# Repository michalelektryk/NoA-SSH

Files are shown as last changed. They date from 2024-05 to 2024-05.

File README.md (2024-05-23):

# Noise of Antimatter - Subshaper
## disclaimer
This repository contains all files required to make or repair the SSH. The following files are provided as is, with no responsibility. They're provided for personal use only. If you'd like to sell anything made out of them feel free to ping me, I'm mostly ok, as long as you're not big company scamming small manufacturers :)
## Module description
SSH is 16HP triple waveshaper with subharmonicon and sequencer. It's versatile tool for enriching sound sources and animating voices. More information can be found on [the webpage](https://noiseofantimatter.com/modules/ssh_module/) or by checking out [the demo](https://www.youtube.com/watch?v=Nd7Cz19s0W0).
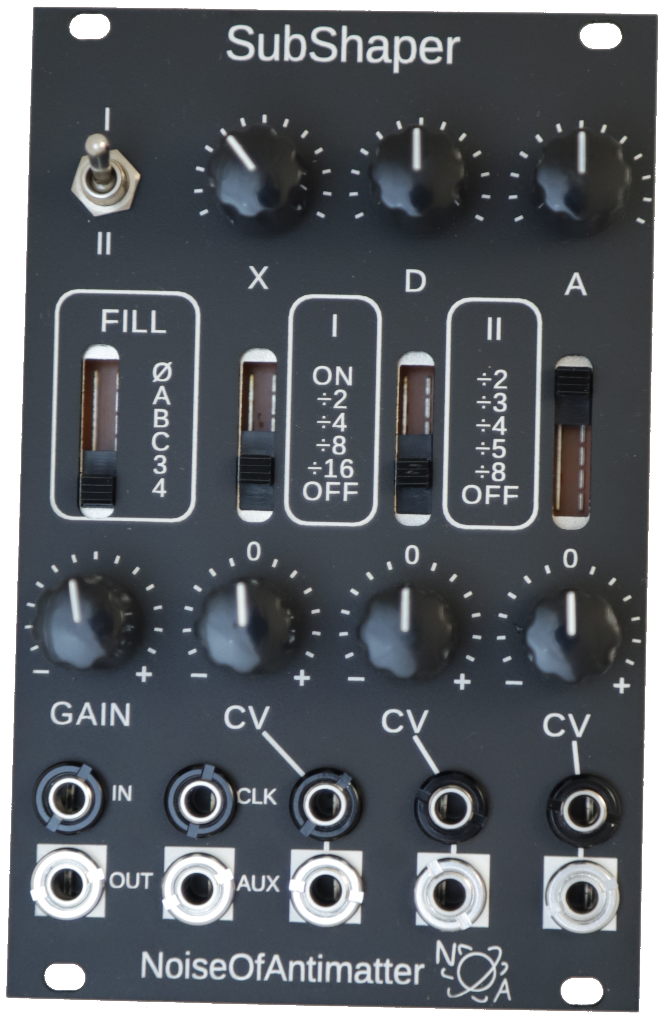
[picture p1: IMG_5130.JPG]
photo of the module


## File structure
- electronics design can be found in folder [electronics](/electronics)
  - schematic.pdf is useful for quick look. For editing and deep dive full kicad design is provided. Project was done in kicad 6 but seems to work equally well in 7/8
- CPDL firmware is provided in folder [greenpak](/greenpak)
  - the device hides all complex digital logic into two greenpak CPLDs.
  - Their configuration and ESP32 software used for flashing are here
- panel design can be found in folder [panel](/panel)
  - panel has been designed as 3d model in openSCAD. Two projections are available for CNC production. Additionally, stls for dual color printing are provided
- manual generating files and pdf can be found in [manual](/manual)
  - It's written in LaTeX. For people who don't know LaTeX I recommend you read about it, especially if you're doing group projects and need to git proper documents

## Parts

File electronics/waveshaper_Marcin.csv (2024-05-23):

Id | Designator | Package | Quantity | Designation | Supplier and ref
1 | U17 | SOT-23-5 | 1 | AP331A
2 | U16,U13 | TSSOP-20_4.4x6.5mm_P0.65mm | 2 | SLG46824
3 | U15,U12,U11,U8,U7,U5,U4,U3,U2,U1 | SOIC-8_3.9x4.9mm_P1.27mm | 10 | TL072
4 | U14 | SOP-16_3.9x9.9mm_P1.27mm | 1 | CD4053B
5 | U10 | SOT-89-3 | 1 | L79L05_SOT89
6 | U9 | SOT-89-3 | 1 | L78L05_SOT89
7 | U6 | SOIC-16_3.9x9.9mm_P1.27mm | 1 | AS3363
8 | SW1 | SS-16F03 | 1 | bank_switch
9 | S4 | SS-16F03 | 1 | channel_3
10 | S3 | SS-16F03 | 1 | channel_2
11 | S2 | SS-16F03 | 1 | channel_1
12 | S1 | SS-16F03 | 1 | fill_switch
13 | RV8 | alpha_pot | 1 | gain
14 | RV7,RV5,RV3,RV1 | alpha_pot | 4 | 10k
15 | RV6,RV4,RV2 | alpha_pot | 3 | param
16 | R71,R69,R66,R64,R63,R62,R61,R60,R59,R57,R54,R53,R52,R51,R50,R49,R48,R47,R36,R34,R26,R23,R22,R21,R20,R19,R18,R17,R16,R14,R13,R12,R11,R10,R9,R8,R7,R6,R5,R4,R3,R2,R1 | R_0603_1608Metric | 43 | 100k
17 | R70,R68,R58,R56 | R_0603_1608Metric | 4 | 400
18 | R67,R46,R37,R32,R30,R29,R28,R27 | R_0603_1608Metric | 8 | 1k
19 | R55,R45,R44,R42,R41,R40,R31,R25,R24 | R_0603_1608Metric | 9 | 10k
20 | R43,R35,R33 | R_0603_1608Metric | 3 | 250k
21 | R39,R38 | R_0603_1608Metric | 2 | 47k
22 | R15 | R_0603_1608Metric | 1 | 20k
23 | JP3,JP2,JP1 | SolderJumper-2_P1.3mm_Open_RoundedPad1.0x1.5mm | 3 | Jumper
24 | J11,J10,J9,J8,J7,J6 | thonkiconn | 6 | AudioJack2_SwitchT
25 | J5 | PinHeader_1x06_P2.54mm_Vertical | 1 | Conn_01x06_Male
26 | J4 | IDC-Header_2x05_P2.54mm_Vertical | 1 | Conn_02x05_Odd_Even
27 | J3 | thonkiconn | 1 | CV3
28 | J2 | thonkiconn | 1 | CV2
29 | J1 | thonkiconn | 1 | CV1
30 | F2,F1 | Fuse_0805_2012Metric | 2 | Polyfuse
31 | D4,D3,D2,D1 | SOT-363_SC-70-6 | 4 | BAV199DW
32 | C27,C26,C25,C24,C21,C20,C19,C18,C15,C14,C13,C12,C2,C1 | C_0603_1608Metric | 14 | 100n
33 | C23,C22,C17,C16 | C_0603_1608Metric | 4 | 100p
34 | C11 | C_0603_1608Metric | 1 | 10u
35 | C10,C9,C8,C7,C6,C5,C4,C3 | C_0805_2012Metric | 8 | 10u

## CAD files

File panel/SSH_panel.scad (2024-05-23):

HP=5.08;
angle=135;
spacing=9.5; //TODO
$fn=20;
draw_jack_plugs=false;

module obwodka(size,diam,width)
{
    difference()
    {
        hull()
        {
            for(x=[diam,size[0]-diam])
            for(y=[diam,size[1]-diam])
                translate([x,y])
                circle(r=diam);
        }
        hull()
        {
            for(x=[diam,size[0]-diam])
            for(y=[diam,size[1]-diam])
                translate([x,y])
                circle(r=diam-width);
        }
    }
}

module panel(n)
{
    difference()
    {
        translate([0.1,0,0])
        cube([n*HP-0.2,128.5,3]);
        for(x=[1.5*HP,(n-1.5)*HP])
        for(y=[3,125.5])
            translate([x,y,-1])
            hull()
            {
                translate([-1,0,0])
                cylinder(r=1.6,h=10);
                translate([1,0,0])
                cylinder(r=1.6,h=10);
            }
    }
}

module jack_in(cut)
{
    if(cut)
        translate([0,0,-1])
        cylinder(d=6.2,h=10);
    else
        translate([0,0,0])
        color("grey")
        difference()
        {
            cylinder(d=6.2,h=4);
            translate([0,0,-1])
            cylinder(d=5,h=6);
        }
}

module jack_out(cut)
{
   
   
    if(cut)
    {  
        translate([0,0,-1])
        cylinder(d=6.2,h=10);
    }
    else
        translate([0,0,0])
        color("grey")
        difference()
        {
            cylinder(d=6.2,h=4);
            translate([0,0,-1])
            cylinder(d=5,h=6);
        }
}


module pot(cut,col="green")
{
    if(cut)
        translate([0,0,-1])
        cylinder(d=7.1,h=10);
    else
        translate([0,0,3.5])
        union()
        {
            color("grey")
            cylinder(d=16,h=4.5);
            color("grey")
            cylinder(d1=13,d2=11,h=17);
            color(col)
            translate([0,4.5,9])
            cube([1.2,4,17],true);
            color(col)
            translate([0,0,15.5])
            intersection()
            {
                cylinder(h=2,d=7);
                translate([0,-3.5,0])
                cube([7,7,7],true);
            }
        }
}

module switch6(cut)
{
    if(cut)
    {
    
    //had to round corners with 3mm radius to deal with milling process    //cube([0.2+3.8+5*3,0.2+4.2,8],true);
        hull()
        for(x=[-0.5,0.5])
        for(y=[-0.5,0.5])
            translate([x*(0.2+3.8+5*3),y*(0.2+4.2-3),-4])
            cylinder(d=3,h=8);
    }
    else
        color("grey")
        translate([0,0,3.5+4.5/2])
        cube([0.2+3.8,0.2+4.2,4.5],true);
       
}

module toggle(cut)
{
    if(cut)
        translate([0,0,-1])
        cylinder(d=6.3,h=10);
    else
        rotate([0,30,90])
        cylinder(d=4,h=10);
}

module arrow_in()
{
    translate([-1,0,0])
    square([3,0.5],true);
    translate([1,0,0])
    for(i=[-1,1])
    rotate(40*i)
    translate([-0.7,0])
    square([1.5,0.5],true);
    difference()
    {
        circle(d=4);
        circle(d=3);
    }
}

module arrow_out()
{
    translate([-1.5,0,0])
    square([3,0.5],true);
    translate([-3.5,0,0])
    for(i=[-1,1])
    rotate(40*i)
    translate([0.7,0])
    square([1.5,0.5],true);
    difference()
    {
        circle(d=4);
        circle(d=3);
    }
}

module opis_atenuv(normalizowane_do_0)
{
    translate([0,spacing])
    if (normalizowane_do_0>0){
        difference()
            {
            text("0",size=2.5,halign="center",valign="center");
            }
        }
    rotate(-angle)
    translate([0,spacing])
    {
        rotate(angle)
        square([2,0.4],true);
        rotate(angle)
        square([0.4,2],true);
    }
    rotate(angle)
    translate([0,spacing])
    {
        rotate(-angle)
        square([2,0.4],true);
    }
}

module opis_galek(not_middle)
{
    ile=6;
    for(i=[-ile:ile])
        if(i!=0 || not_middle<1)
            rotate(i*angle/(ile+1))
            translate([0,spacing-1])
            square([0.4,1],true);
}

switch_level=73;
lower_element=48;
higher_element=105;

module elementy_sub(cut)
{
    for(x=[1:3])
        translate([HP*(2+4*x),0,0])
        {
            translate([0,lower_element,0])
            pot(cut);
            translate([0,switch_level,0])
            rotate([0,0,90])
            switch6(cut);
            translate([0,higher_element,0])
            pot(cut);
        }        
    translate([HP*2,switch_level,0])
    rotate([0,0,90])
    switch6(cut);
    translate([HP*2,higher_element,0])
    toggle(cut);
    translate([HP*2,lower_element,0])
    pot(cut);
    for(x=[0:4])
    {
        translate([16/5*HP*(0.5+x),15,0])
        {
        jack_out(cut);
        if(draw_jack_plugs)
            color("blue")
            cylinder(d=10,h=15);
       
        }
        translate([16/5*HP*(0.5+x),26,0])
        jack_in(cut);
       
       
    }
   
}

SSH_font="Latin modern";

//off spaces to U+2006  SIX-PER-EM SPACE
bankA=["ON","÷2","÷4","÷8","÷16","OFF"];
bankB=["÷2","÷3","÷4","÷5","÷8","OFF"];
control=["Ø","X","D","A","3","4"];
switch=["II","I"];
param=["X","D","A"];
higher_jacks=["IN", "CLK"];
lower_jacks=["OUT", "AUX"];
dodatek=7;

module napisy()
//wszystkie napisy ida tutaj!!!
translate([0,0,3])
linear_extrude(0.2)
{
    opisyBankowSize=2.5;
    //bank 1 slider opisy
    for(i=[0:5])
        translate([HP*8,switch_level-3*(i-2.5)])
        text(bankA[i],size=opisyBankowSize,halign="center",valign="center",spacing=1.1);
    translate([HP*8,switch_level+14])
    text(switch[1],size=3,halign="center",valign="center");
    //bank 2 slider opisy
    for(i=[0:5])
        translate([HP*12,switch_level-3*(i-2.5)])
        text(bankB[i],size=opisyBankowSize,halign="center",valign="center",spacing=1.1);
    translate([HP*12,switch_level+14])
    text(switch[0],size=3,halign="center",valign="center");
    //control slider opisy
    for(i=[0:5])
        translate([HP*4-2,switch_level-3*(i-2.5)])
        text(control[i],size=opisyBankowSize,halign="center",valign="center",spacing=1.1);
    //control slider napis
    translate([HP*3+5.25/2-dodatek/2,switch_level+14])
    text("FILL",size=3,halign="center",valign="center",spacing=1.1);
    //bank switch napisy
    for(i=[0,1])
        translate([HP*2,higher_element-8+8*2*i])
        text(switch[i],size=3,halign="center",valign="center");
    /*translate([HP*2-5,higher_element])
    text("BANK",size=3,halign="center",valign="center",direction="ttb");*/
    //napisy pod atenuvertery
    for(i=[0:3])
    translate([HP*(2+4*i),lower_element])
    {
        if(i!=0)
            translate([0,-12])
            text("CV",size=3,halign="center",valign="center",spacing=1.1);
        else
            translate([0,-12])
            text("GAIN",size=3,halign="center",valign="center",spacing=1.1);
        opis_atenuv(i);
        opis_galek(i);
    }
    //napisy pod parametrowe galki
    for(i=[0:2])
    translate([HP*(2+4+4*i),higher_element])
    {
        translate([0,-12])
        text(param[i],size=3,halign="center",valign="center");
        opis_galek(0);
    }
   
   
    //kreski
    translate([HP*(2+4*3)+0.7,lower_element-14])
    color("white")
    rotate(-83)
    square([5,0.5],false);
   
    translate([HP*(2+4*2)+1,lower_element-14])
    color("white")
    rotate(-57)
    square([7,0.5],false);
   
    translate([HP*(2+4)+2,lower_element-14])
    color("white")
    rotate(-45)
    square([9,0.5],false);
   
    difference()
    {
    for(x=[0:4])
        {
        translate([16/5*HP*(0.5+x),15,0])
        square([9,9],true);
        }
    }
    //opisy jackow out
    for(i=[0:1])
    {
    translate([16/5*HP*(i+1)-3.2,15])
    text(lower_jacks[i],size=2,halign="left",valign="center");
    //opisy jackow in
    translate([16/5*HP*(i+1)-3.2,26])
    text(higher_jacks[i],size=2,halign="left",valign="center");
    }
   
   
    for (i=[2:4])
    {
    //linie jacki in-out
    translate([16/5*HP*(0.5+i),21,0])
            square([0.5,4],true);  
    }
    //TESTS
   
    NOA_text=["NoiseOfAntimatter", "Noise Of Antimatter", "Noise of Antimatter", "NOA", "NoA"];
    NOA_nr=0;
    SSH_text=["SSH", "SubShaper"];
    SSH_nr=1;
    SSH_size=[3.3,4.5];
    Pozycjonowanie=1;


    if (Pozycjonowanie==0){
       
        SSH_offset=[0,-HP-2];

        color("white")
        translate([8*HP+SSH_offset[SSH_nr],121,0])
        text(SSH_text[SSH_nr], halign="center", size=SSH_size[SSH_nr], font=SSH_font);
   
        color("white")
        translate([11*HP+2,117,0])
        import(file = "Logo.svg", dpi = 900);

        color("white")
        translate([8*HP,4,0])
        text(NOA_text[NOA_nr],halign="center", size=3.3);
}
else if (Pozycjonowanie==1){
NOA_size=[3.3, 3.3, 3.3, 3.3, 3.3];
NOA_offset=[-5,-3, -3, -1.5, -1.5];
   
   
color("white")
translate([8*HP,121,0])
text(SSH_text[SSH_nr],font=SSH_font, halign="center", size=SSH_size[SSH_nr]);

color("white")
translate([8*HP+NOA_offset[NOA_nr],3,0])
text(NOA_text[NOA_nr],halign="center", size=3.3);

color("white")
translate([11.5*HP-3,1,0])
import(file = "Logo.svg", dpi = 1200);
}
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

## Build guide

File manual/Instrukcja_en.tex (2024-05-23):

\documentclass[a4paper,14pt]{extarticle}
\usepackage[utf8]{inputenc}
\usepackage{helvet}
\usepackage{xcolor}
\usepackage{titlesec}
\usepackage{multicol}
\usepackage{geometry} 
\usepackage{wrapfig}
\usepackage{lipsum} 
\usepackage{pdfpages}

%TODO
%patch ideas logo
%patch ideas keep white but change font or bold
%new photo of ribbon, or (preferably) some schematic/diagram

\newgeometry{tmargin=0.5cm, bmargin=0.5cm, lmargin=0.5cm, rmargin=1cm} 
\renewcommand{\familydefault}{\sfdefault}
\definecolor{sectcolor}{rgb}{0.9,0.9,0.9}
\definecolor{Xcolor}{rgb}{0.91015625 , 0.015625, 0.015625}
\definecolor{Dcolor}{rgb}{0.0078125  , 0.                  , 0.41015625}
\definecolor{Acolor}{rgb}{0.03515625, 0.32421875, 0.01171875}
\definecolor{division_color}{rgb}{0.5,0.0,0.5}

\titleformat{\section}
  {\normalfont\LARGE\selectfont\bfseries}
  {\llap{\colorbox{sectcolor}{%
    \makebox[1.4cm][r]{%
      \makebox[0.7cm][l]{\thesection.\hfill}}%
      }\hspace{10pt}%
    }%
  }
  {0em}
  {}

\titleformat{\subsection}
  {\normalfont\Large\bfseries}
  {\llap{\colorbox{white}{%
    \makebox[1.4cm][r]{%
      \makebox[0.7cm][l]{\thesubsection\hfill}}%
      }\hspace{10pt}%
    }%
  }
  {0em}
  {}

\newlength\myboxwidth

\setlength{\myboxwidth}{\dimexpr\textwidth-0\fboxsep}
\definecolor{patchIdeasColor}{rgb}{0.3,0.3,0.3}

\begin{document}

\begin{flushright}

\end{flushright}
{\huge\textbf{SubShaper user manual}}\\*
\section*{What is SubShaper}
The module's name is a combination of two words, "Subharmonics" and "Waveshaper." This name reflects the two main functional parts of the module: waveshaping channels that add harmonics and clock dividers that introduce subharmonics.
\section*{Inputs and Outputs}

\begin{center}

\end{center}
Module has \textbf{10 jacks}, divided into \textbf{2 groups}: on the left there are \textbf{4 common I/O} and on the right \textbf{3 modulation inputs} and \textbf{3 individual outputs}.

\begin{center}

\end{center}

\section*{Behavior}

From left to right, waveshaper channels are:
\begin{itemize}
\item \textcolor{Xcolor}{X - crossover distortion}: This waveshaper simulates a class B amplifier that distorts the signal more as it gets quieter. "It can be considered the opposite of typical saturation/limiter distortion."\\


\item \textcolor{Dcolor}{D - frequency doubler}: As the name suggests, this waveshaper generates a wave at double the frequency of the input wave (at least for a sine wave). For a triangle wave, it generates a parabolic-like shape. This waveshaper is particularly useful for adding "soft" harmonics to the signal.\\


%\item \textcolor{Acolor}{A - absolute value}, it rectifies the signal. The knob goes from folding the top half bottom to letting the signal through to folding the bottom half up. Selectivelly change amplification of either half of the signal.\\
\item \textcolor{Acolor}{A - absolute value}, it allows you to selectively amplify and/or invert either half input wave. In it's middle position it let's the signal through, going counterclockwise it bends bottom half up to positive values while going clockwise bends top half down towards negative values.\\


\end{itemize}
\vspace{0.5cm}
\fcolorbox{patchIdeasColor}{patchIdeasColor}{
\begin{minipage}{\myboxwidth}
\textcolor{white}{(patch idea):  To better understand the effect of waveshapers we recommend sending audio to IN and listening to output from single channels individually}
\end{minipage}}
\\
\vspace{0.5cm}
\\
\fcolorbox{patchIdeasColor}{patchIdeasColor}{
\begin{minipage}{\myboxwidth}
\textcolor{white}{(patch idea):  Waveshaper channels can also be used independently for adding 3 new waveforms to your favourite VCO or LFO.}
\end{minipage}}
\vspace{0.5cm}
\\
Each waveshaper has a controllable parameter that can be modulated using CV (Control Voltage). Signal from modulation jack goes through attenuverter and gets summed with knob at the top. Modulation inputs accept audio rate modulation allowing for many interesting effects, including MI Warps like wave mixing or self modulation where one waveshaper channel modulates the other.
\\
Note that outputs from waveshapers are not influenced by clock divisions.
\vspace{0.5cm}
\\
\fcolorbox{patchIdeasColor}{patchIdeasColor}{
\begin{minipage}{\myboxwidth}
\textcolor{white}{(patch idea):  Try using output of abs to modulate doubler. Change modulation depth and polarity by rotating doubler attenuverter. You can keep it simple or go wild with multiple feedback loops.}
\end{minipage}}
\vspace{0.5cm}
\\
Clock divisions can be set for each channel using the \textcolor{division_color}{slide switches}. There are \textbf{2 banks} of selections, one for \textbf{simpler, more octave} sounds, one for more \textbf{complicated harmonic structures}. All 3 switches have to work in the same bank. The clock dividers are stateless. It means that any switch changes immediately reflected at the output. If one switches from one clock division that was off to the other that was on results show up instantly, not waiting for next clock period. It's important as it keeps channels in sync and predictable when live patching.
\vspace{0.5cm}
\\
\fcolorbox{patchIdeasColor}{patchIdeasColor}{
\begin{minipage}{\myboxwidth}
\textcolor{white}{(patch idea): AUX doesn't use switches so comparing it to OUT is good starting point to grasp inner working of dividers. For Simplicity we recommend setting 2 channels to off and fill to Ø to start with one channel at the time.}
\end{minipage}}
\vspace{0.5cm}
\\
\textcolor{division_color}{Clock dividers} get clocked by CLK that is normalised to IN. Thanks to that normalisation subharmonics can be generated with just default internal routing. This normalisation can be broken by inserting any jack into CLK. It's useful for low frequency waveshaper switching, ring modulating one oscillator with another or delaying/phase shifting square wave from VCO. Logic high threshold is set to around 1.2V, counters get advanced on every rising edge of input clock/gate. Thanks to that module can be patched with both gates and triggers.
\vspace{0.5cm}
\\
\fcolorbox{patchIdeasColor}{patchIdeasColor}{
\begin{minipage}{\myboxwidth}
\textcolor{white}{(patch idea): Try enabling just one channel (like in previous patch) and patch slow LFO into CLK. You'll hear signal being on and off. By speeding up LFO one gets into ringmod like terythory. }
\end{minipage}}
\vspace{0.5cm}
\\
Clock dividers can be on or off, and there may be instances when all channels are turned off and aligned, resulting in no audio output. This can be undesirable, particularly when using slow modulation clocks.  o address this, we have introduced the \textbf{FILL switch}. This switch allows you to choose what happens during periods of silence in the output. You can select to fill the silence with either the X channel (marked as A on the first revision of panels), the D channel (marked as B on the first revision of panels),  the A channel (marked as C on the first revision of panels) or modes 3 or 4. The 3 and 4 modes require further explanation. In the 3 mode, the gaps will be filled alternately with \textcolor{Xcolor}{X}, \textcolor{Dcolor}{D}, \textcolor{Acolor}{A},\textcolor{Xcolor}{X}, \textcolor{Dcolor}{D}, \textcolor{Acolor}{A}, repeating in that sequence. In the 4 mode, silence will be reintroduced at the output every fourth division, following the pattern \textcolor{Xcolor}{X}, \textcolor{Dcolor}{D}, \textcolor{Acolor}{A}, Ø, \textcolor{Xcolor}{X}, \textcolor{Dcolor}{D}, \textcolor{Acolor}{A}, Ø, and so on.

\section*{Installation}
SSH requires standard eurorack power supply, on 10 pin IDC connector. The red stripe of the ribbon cable (-12V side) must be oriented to the bottom of the module, in the direction when inner PCB ends, in the direction of jacks. In case of big resistance during connection of power supply connector should
be supported from other side, to avoid applying excessive pressure to PCB and damaging it. Module draws up to \textbf{100mA} of current from both supply rails. Module should be screwed with 4 bolts into compatible eurorack case prior to any patching, otherwise damage may occur due to excessive forces. Nylon washers are recommended if one wishes to not scratch powder coating on panel, so called rackrash.
\\
%\begin{center}
%\includegraphics[width=0.5\textwidth,angle=90]{./tasiemka.jpg}
%\end{center}

\section*{Warranty}
Module is covered with 2-years warranty since day of purchase. Warranty does not cover malfunction caused by incorrect use (such as reverse power connection, excessive voltage levels, bad weather conditions, or physical damages). This warranty covers defects resulting from the manufacturing of this product only. Before sending module to service, please contact us at support@noiseofantimatter.com\\
If your warranty expired or malfunction is result of users actions feel free to contact us for out-of-warranty service and/or self-service help.
\section*{EMC compliance}
Noise of antimatter verifies that a properly constructed modular system, adhering to the Doepfer standard, based on cases, power supplies, power distribution boards and a coherent selection of modules, available from other manufacturers meets the requirements defined by international certification bodies.\\

In the paragraphs that follow, Device refers to the Eurorack module, properly installed, powered, and patched as part of a system.\\
This device complies with Part 15 of the FCC Rules. Operation is subject to the following two conditions: (1) this device may not cause harmful interference, and (2) this device must accept any interference received, including interference that may cause undesired operation.\\
Changes / modifications could void the user’s authority to operate the equipment.
\\
This device meets the requirements of the following standards:
\begin{itemize}
\item    EN55032. Electromagnetic compatibility of multimedia equipment. Emission requirements.
\item    EN55103-2. Electromagnetic compatibility - Product family standard for audio, video, audio-visual and entertainment lighting control apparatus for professional use.
\item    EN61000-3-2. Limits for harmonic current emissions (equipment input current $\leq$ 16 A per phase).
\item    EN61000-3-3. Limitation of voltage changes, voltage fluctuations and flicker in public low-voltage supply systems, for equipment with rated current $\leq$ 16 A per phase and not subject to conditional connection.
\item    EN62311. Assessment of electronic and electrical equipment related to human exposure restrictions for electromagnetic fields (0 Hz - 300 GHz).
\end{itemize}

\end{document}

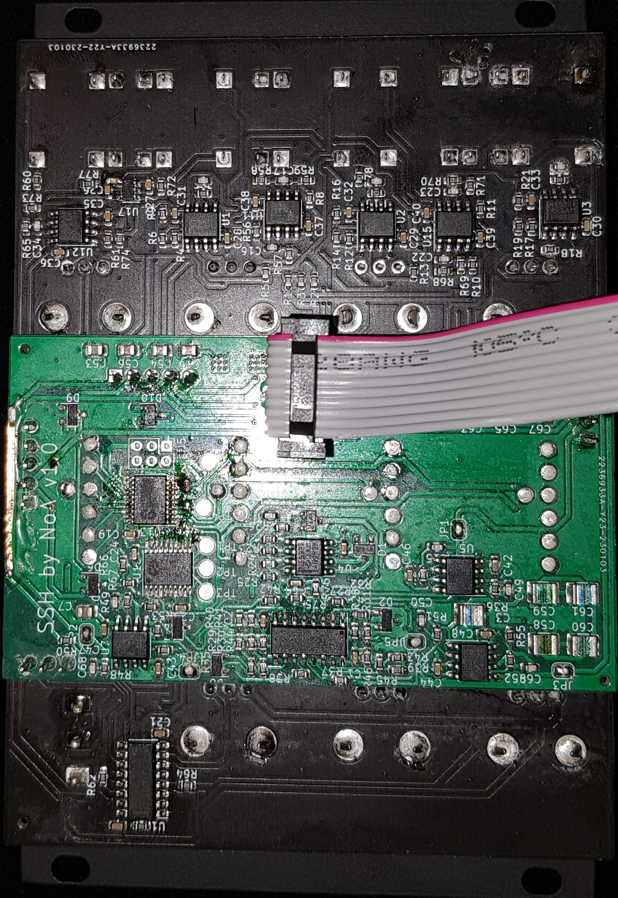
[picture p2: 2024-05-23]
manual/tasiemka.jpg

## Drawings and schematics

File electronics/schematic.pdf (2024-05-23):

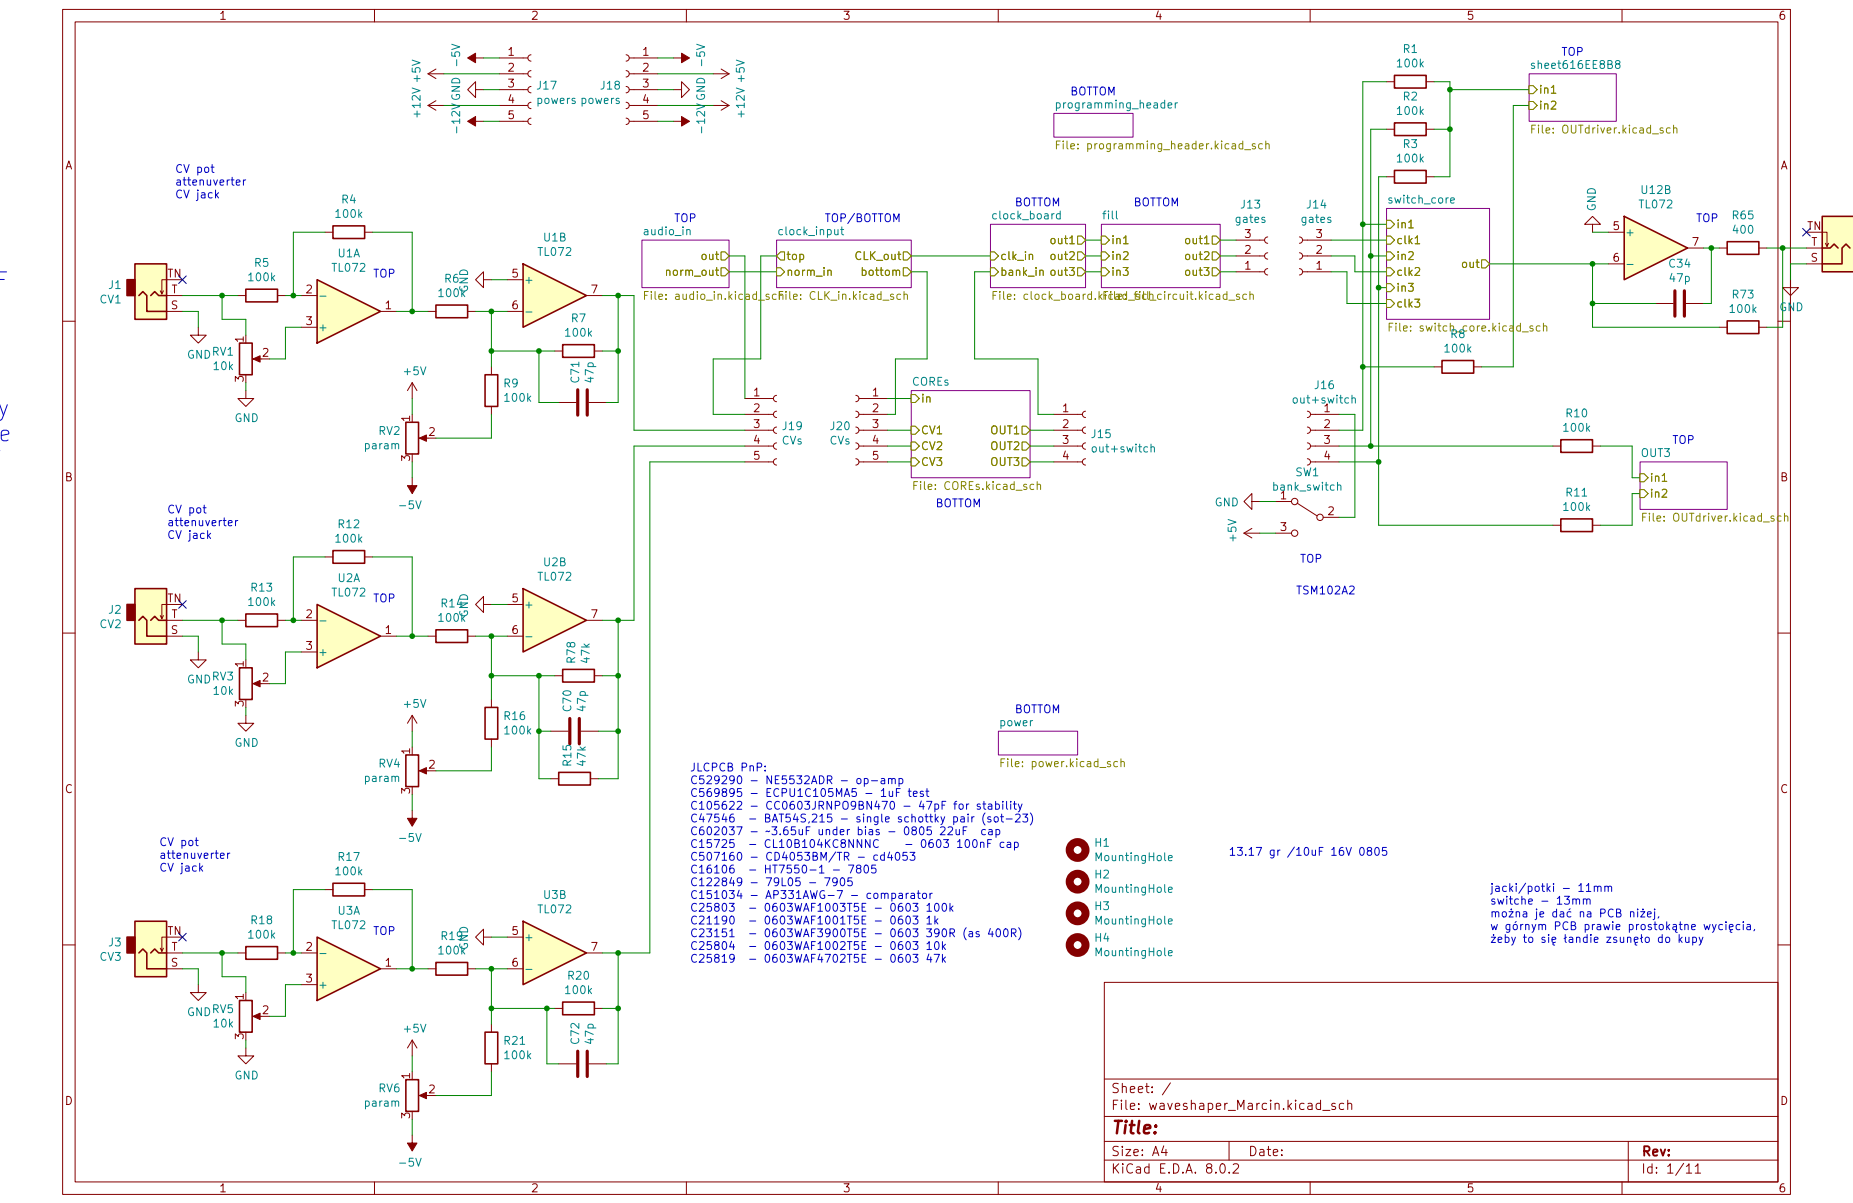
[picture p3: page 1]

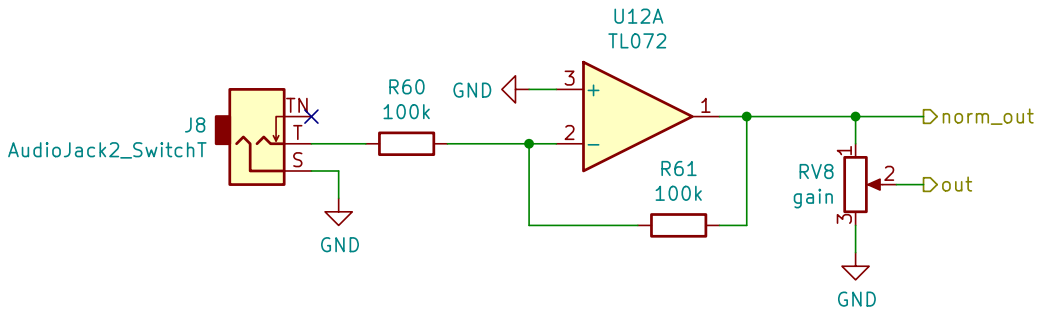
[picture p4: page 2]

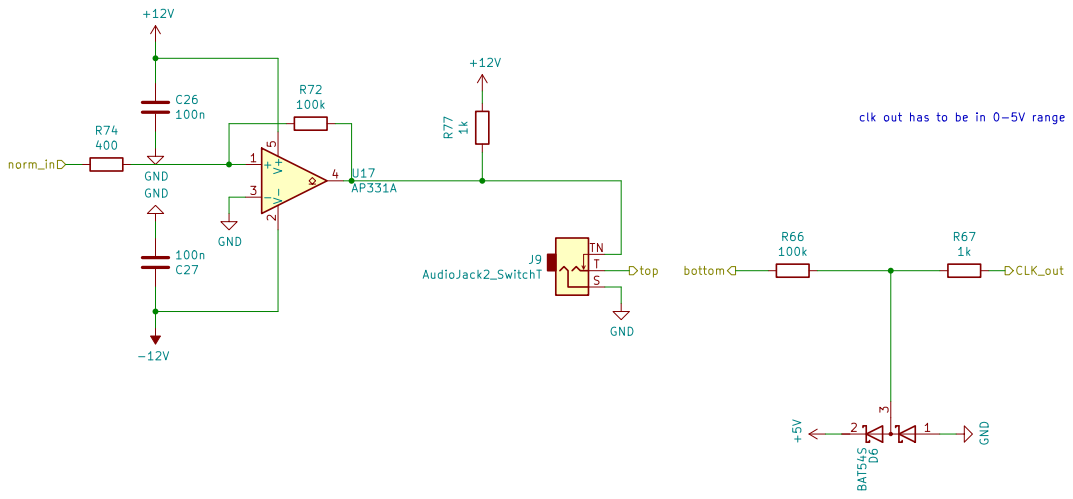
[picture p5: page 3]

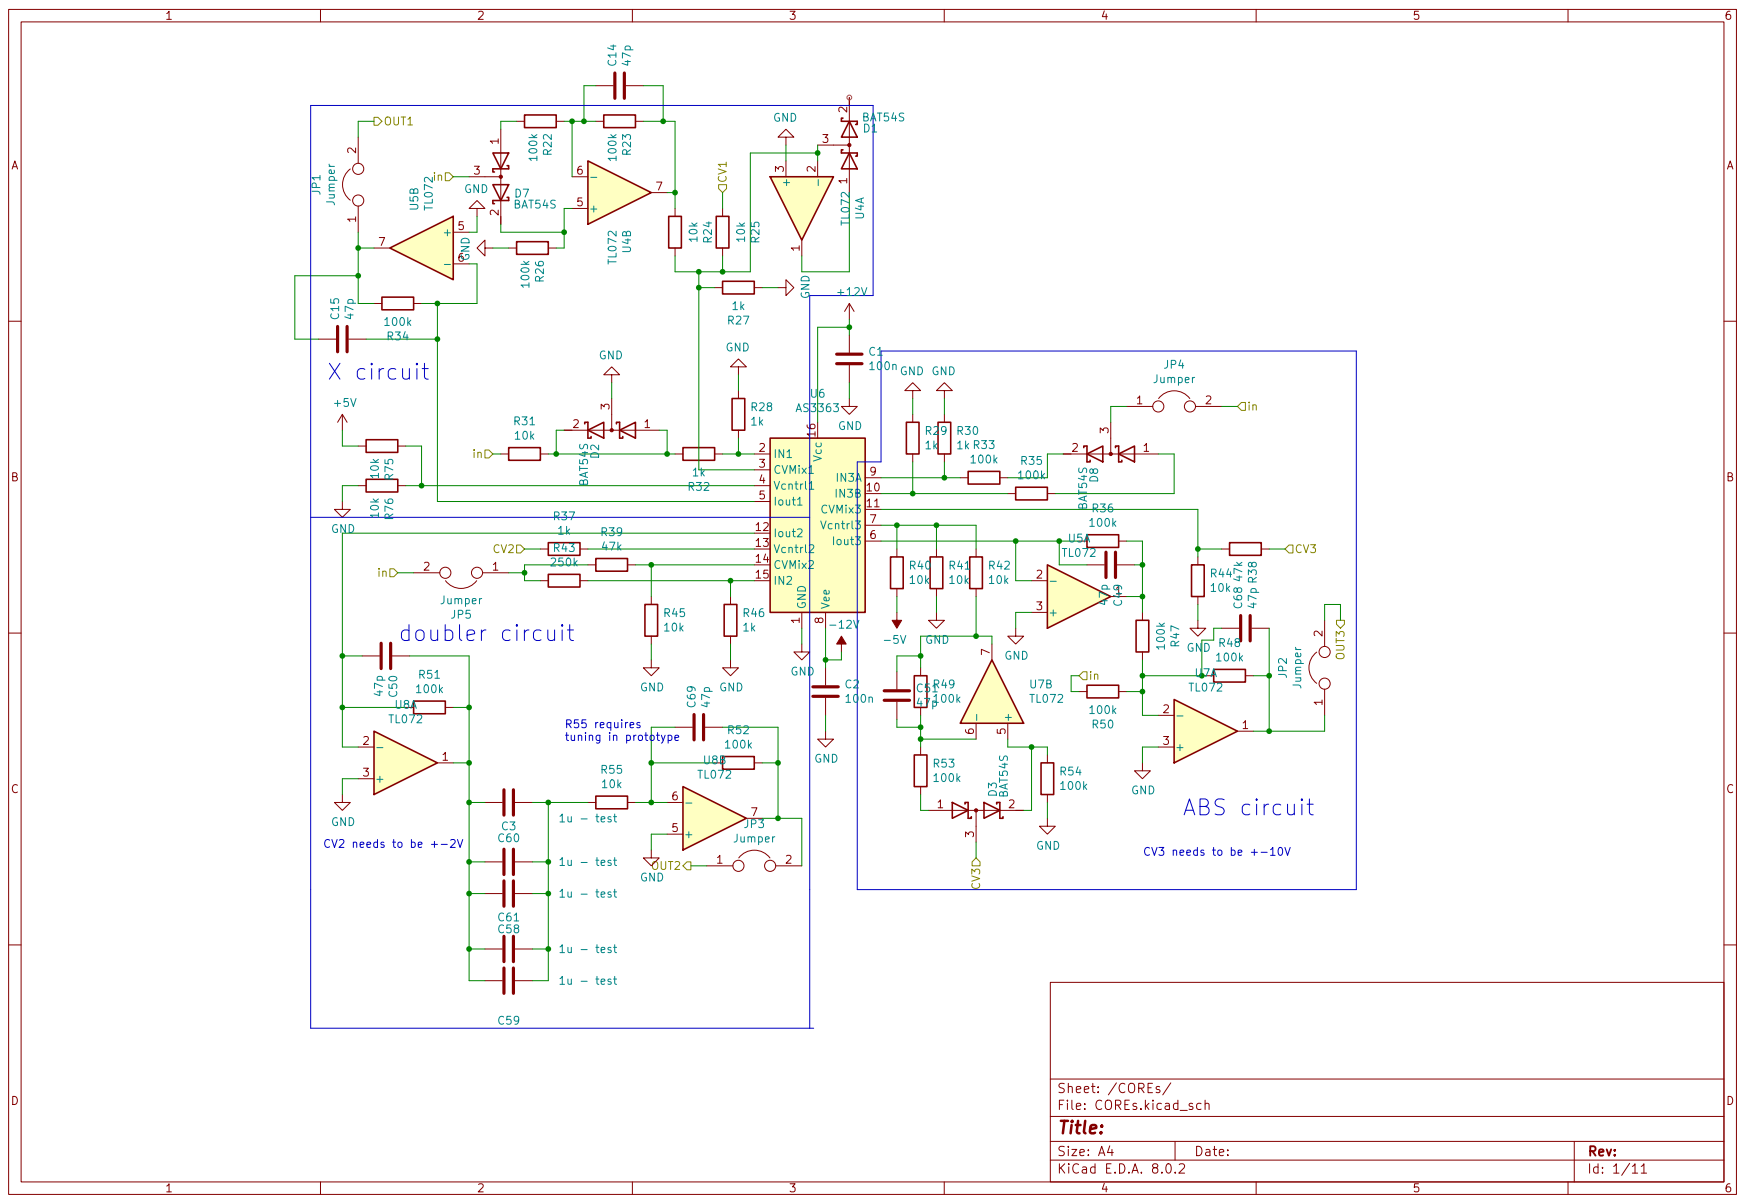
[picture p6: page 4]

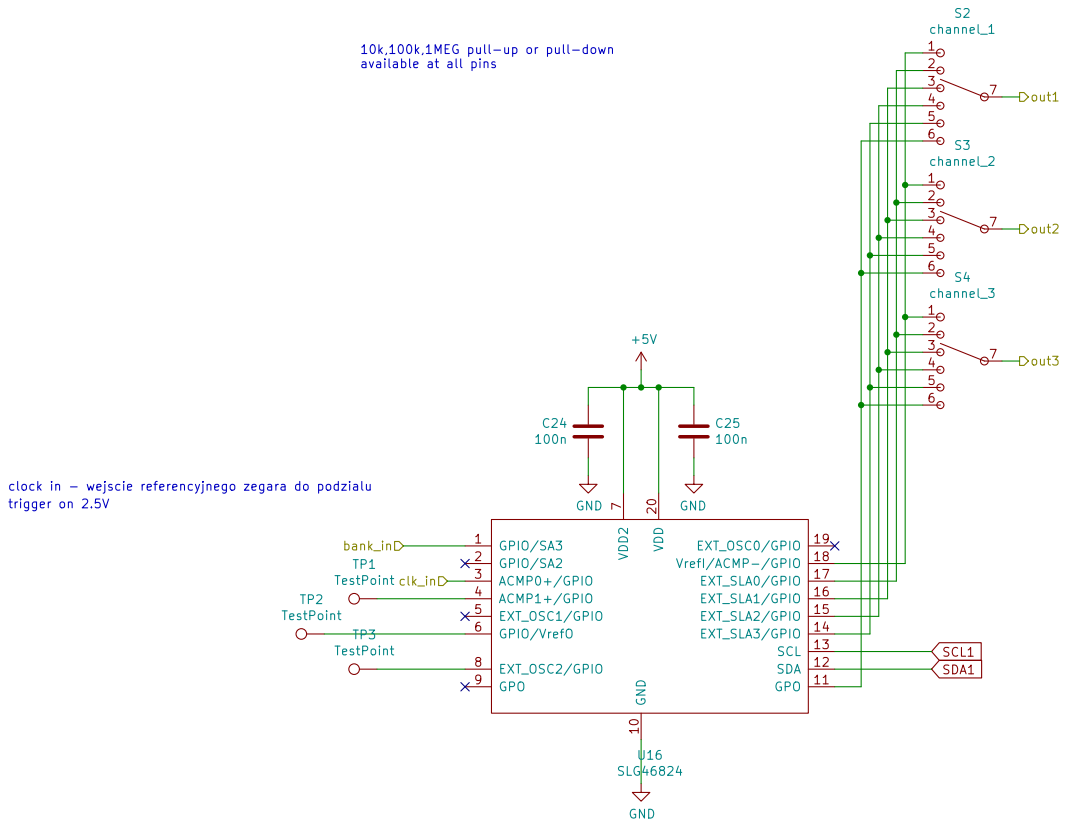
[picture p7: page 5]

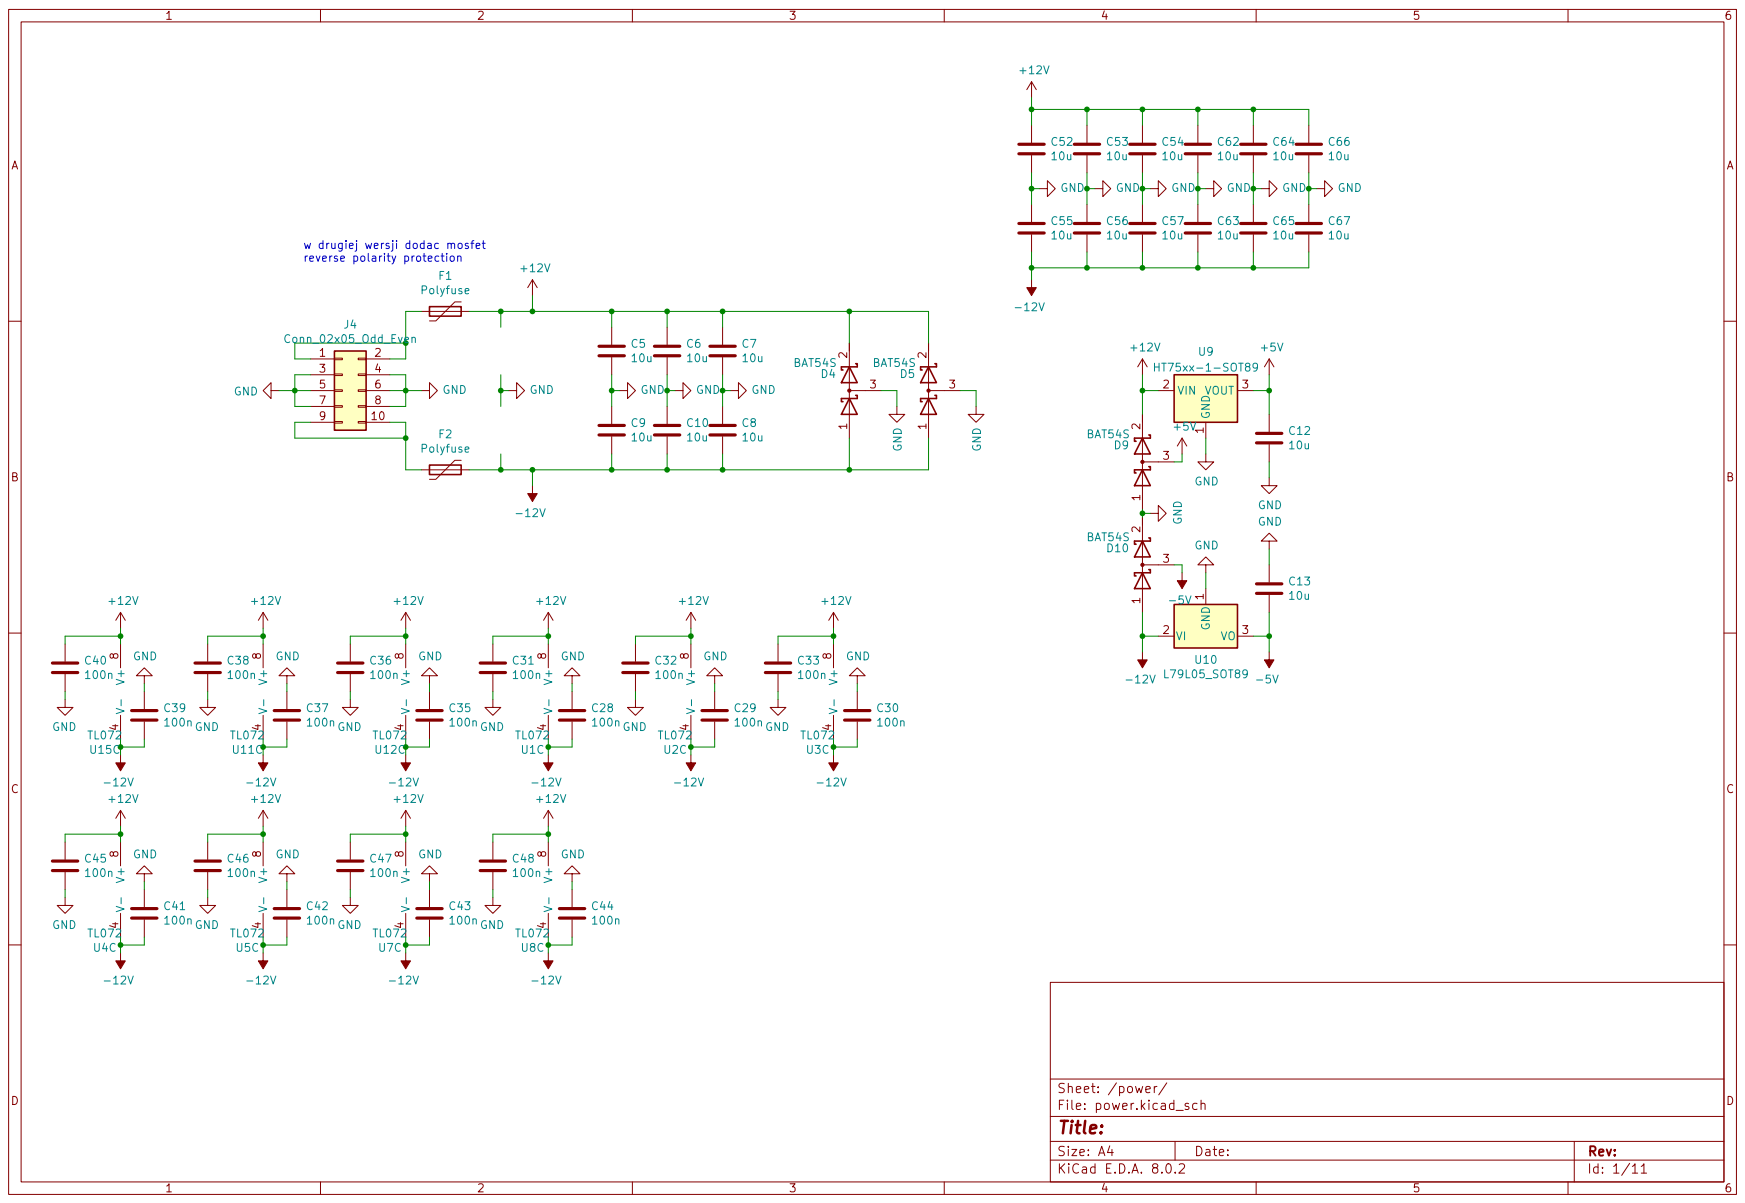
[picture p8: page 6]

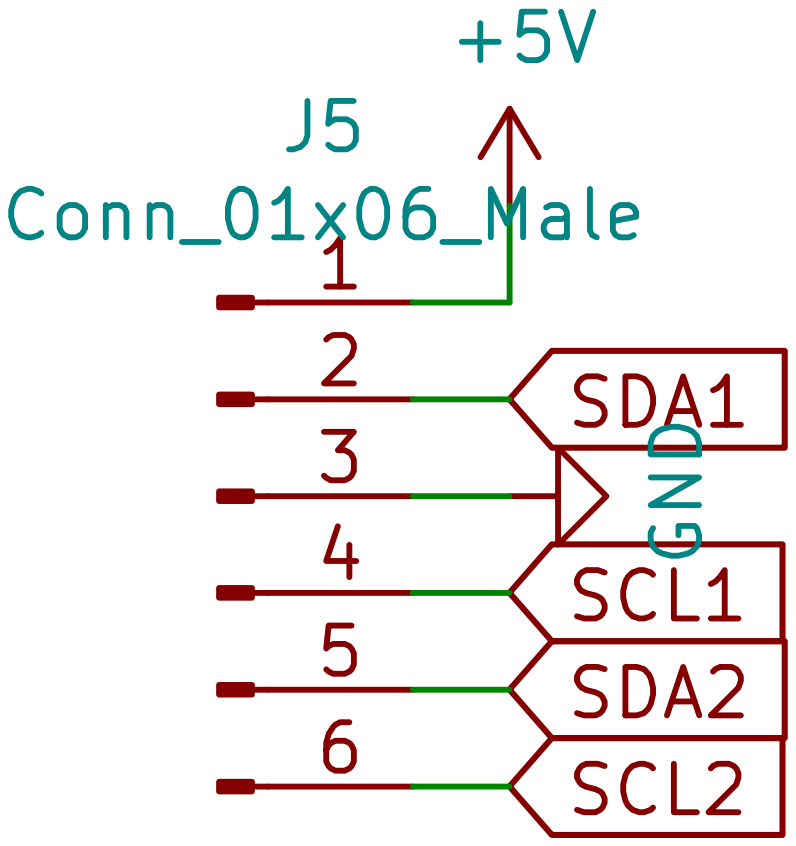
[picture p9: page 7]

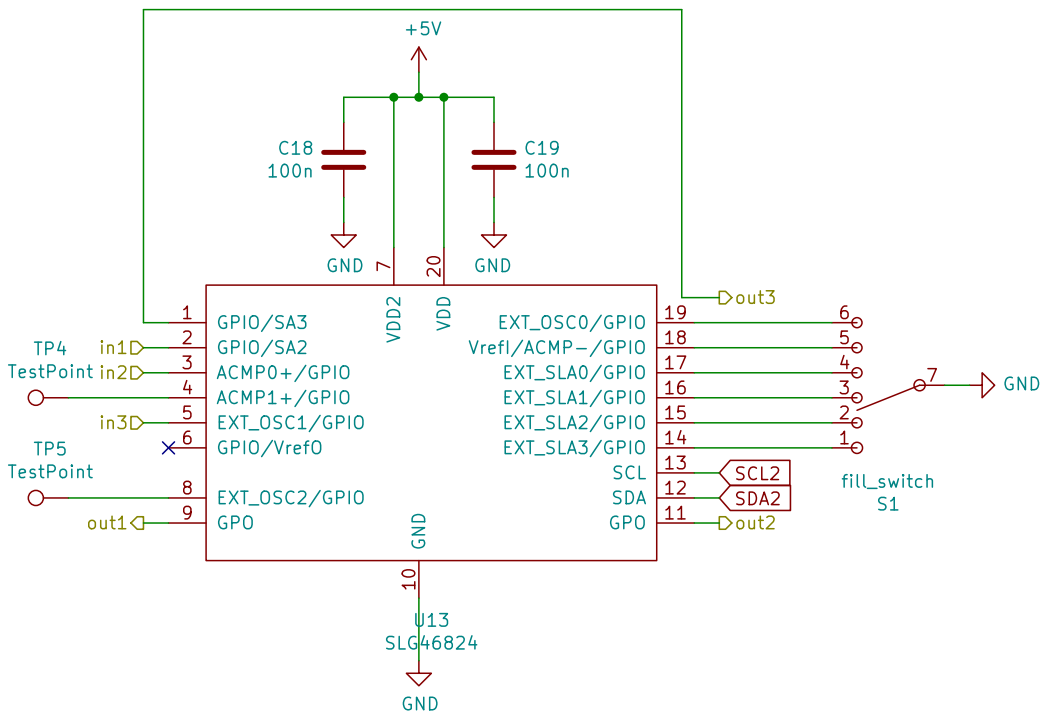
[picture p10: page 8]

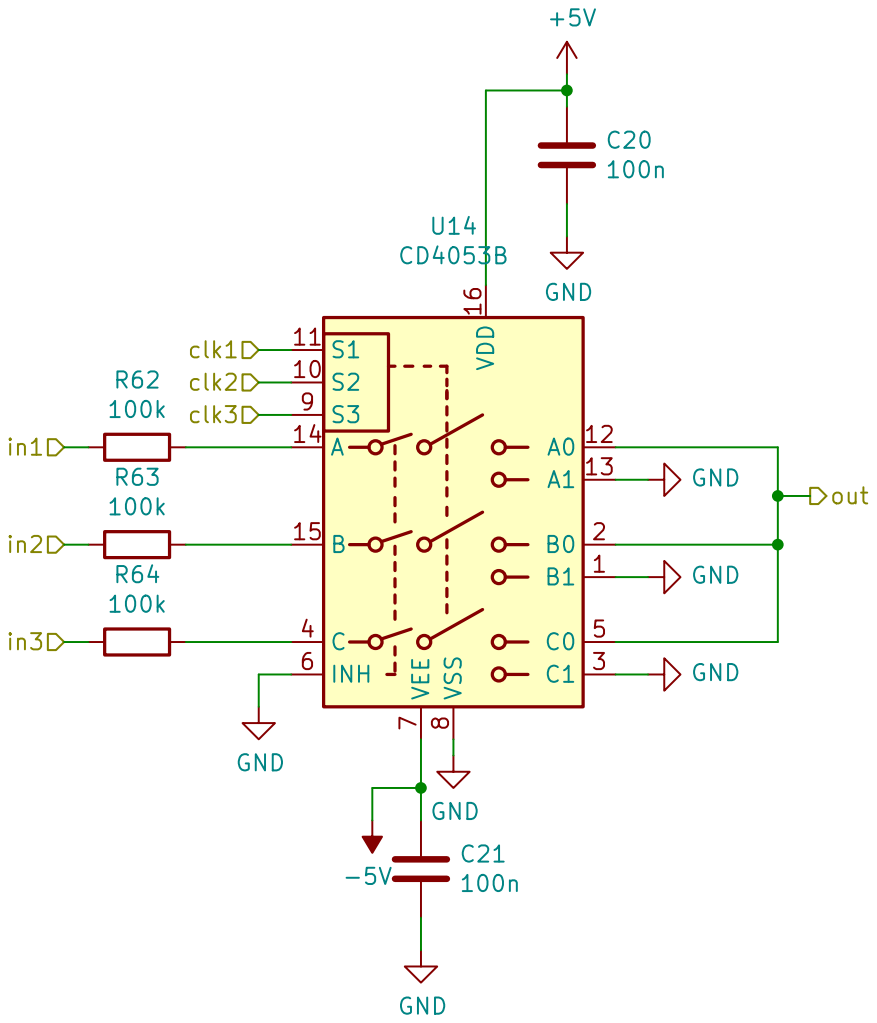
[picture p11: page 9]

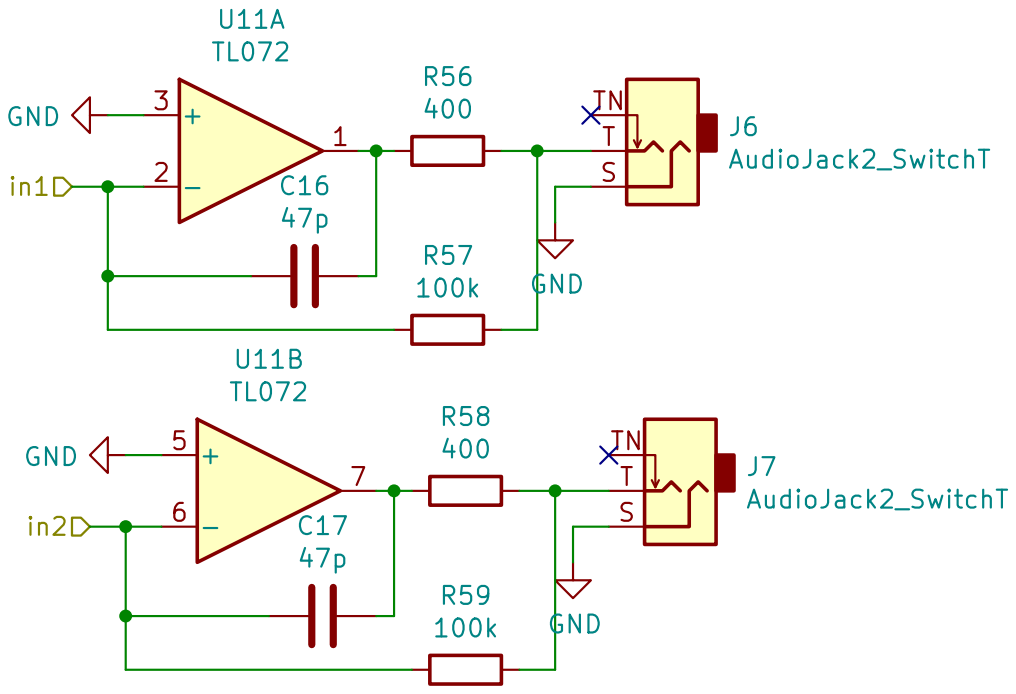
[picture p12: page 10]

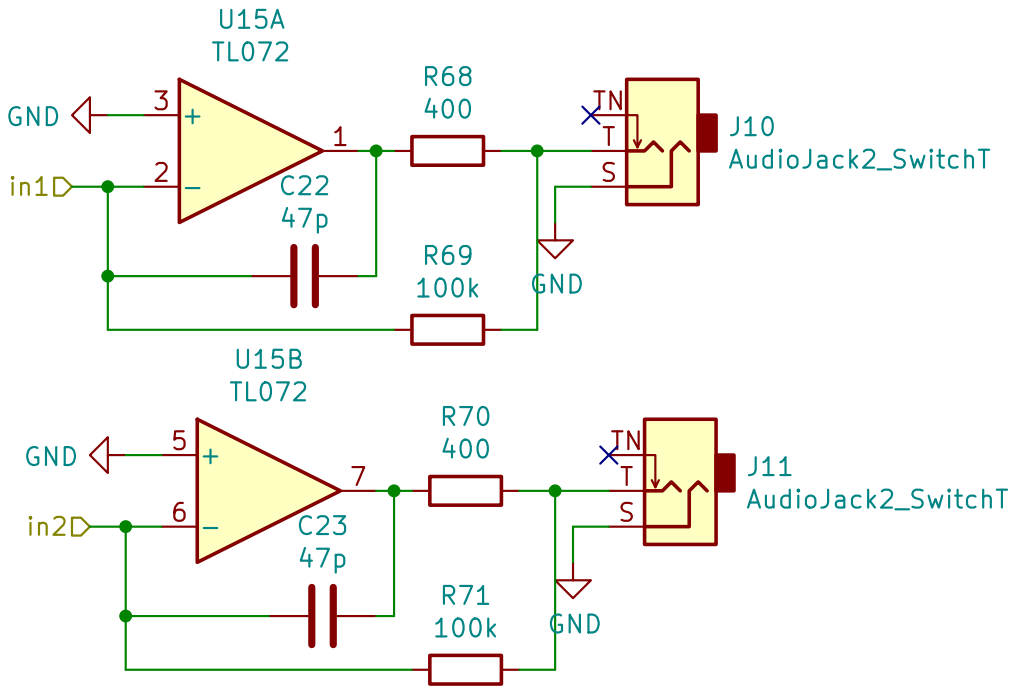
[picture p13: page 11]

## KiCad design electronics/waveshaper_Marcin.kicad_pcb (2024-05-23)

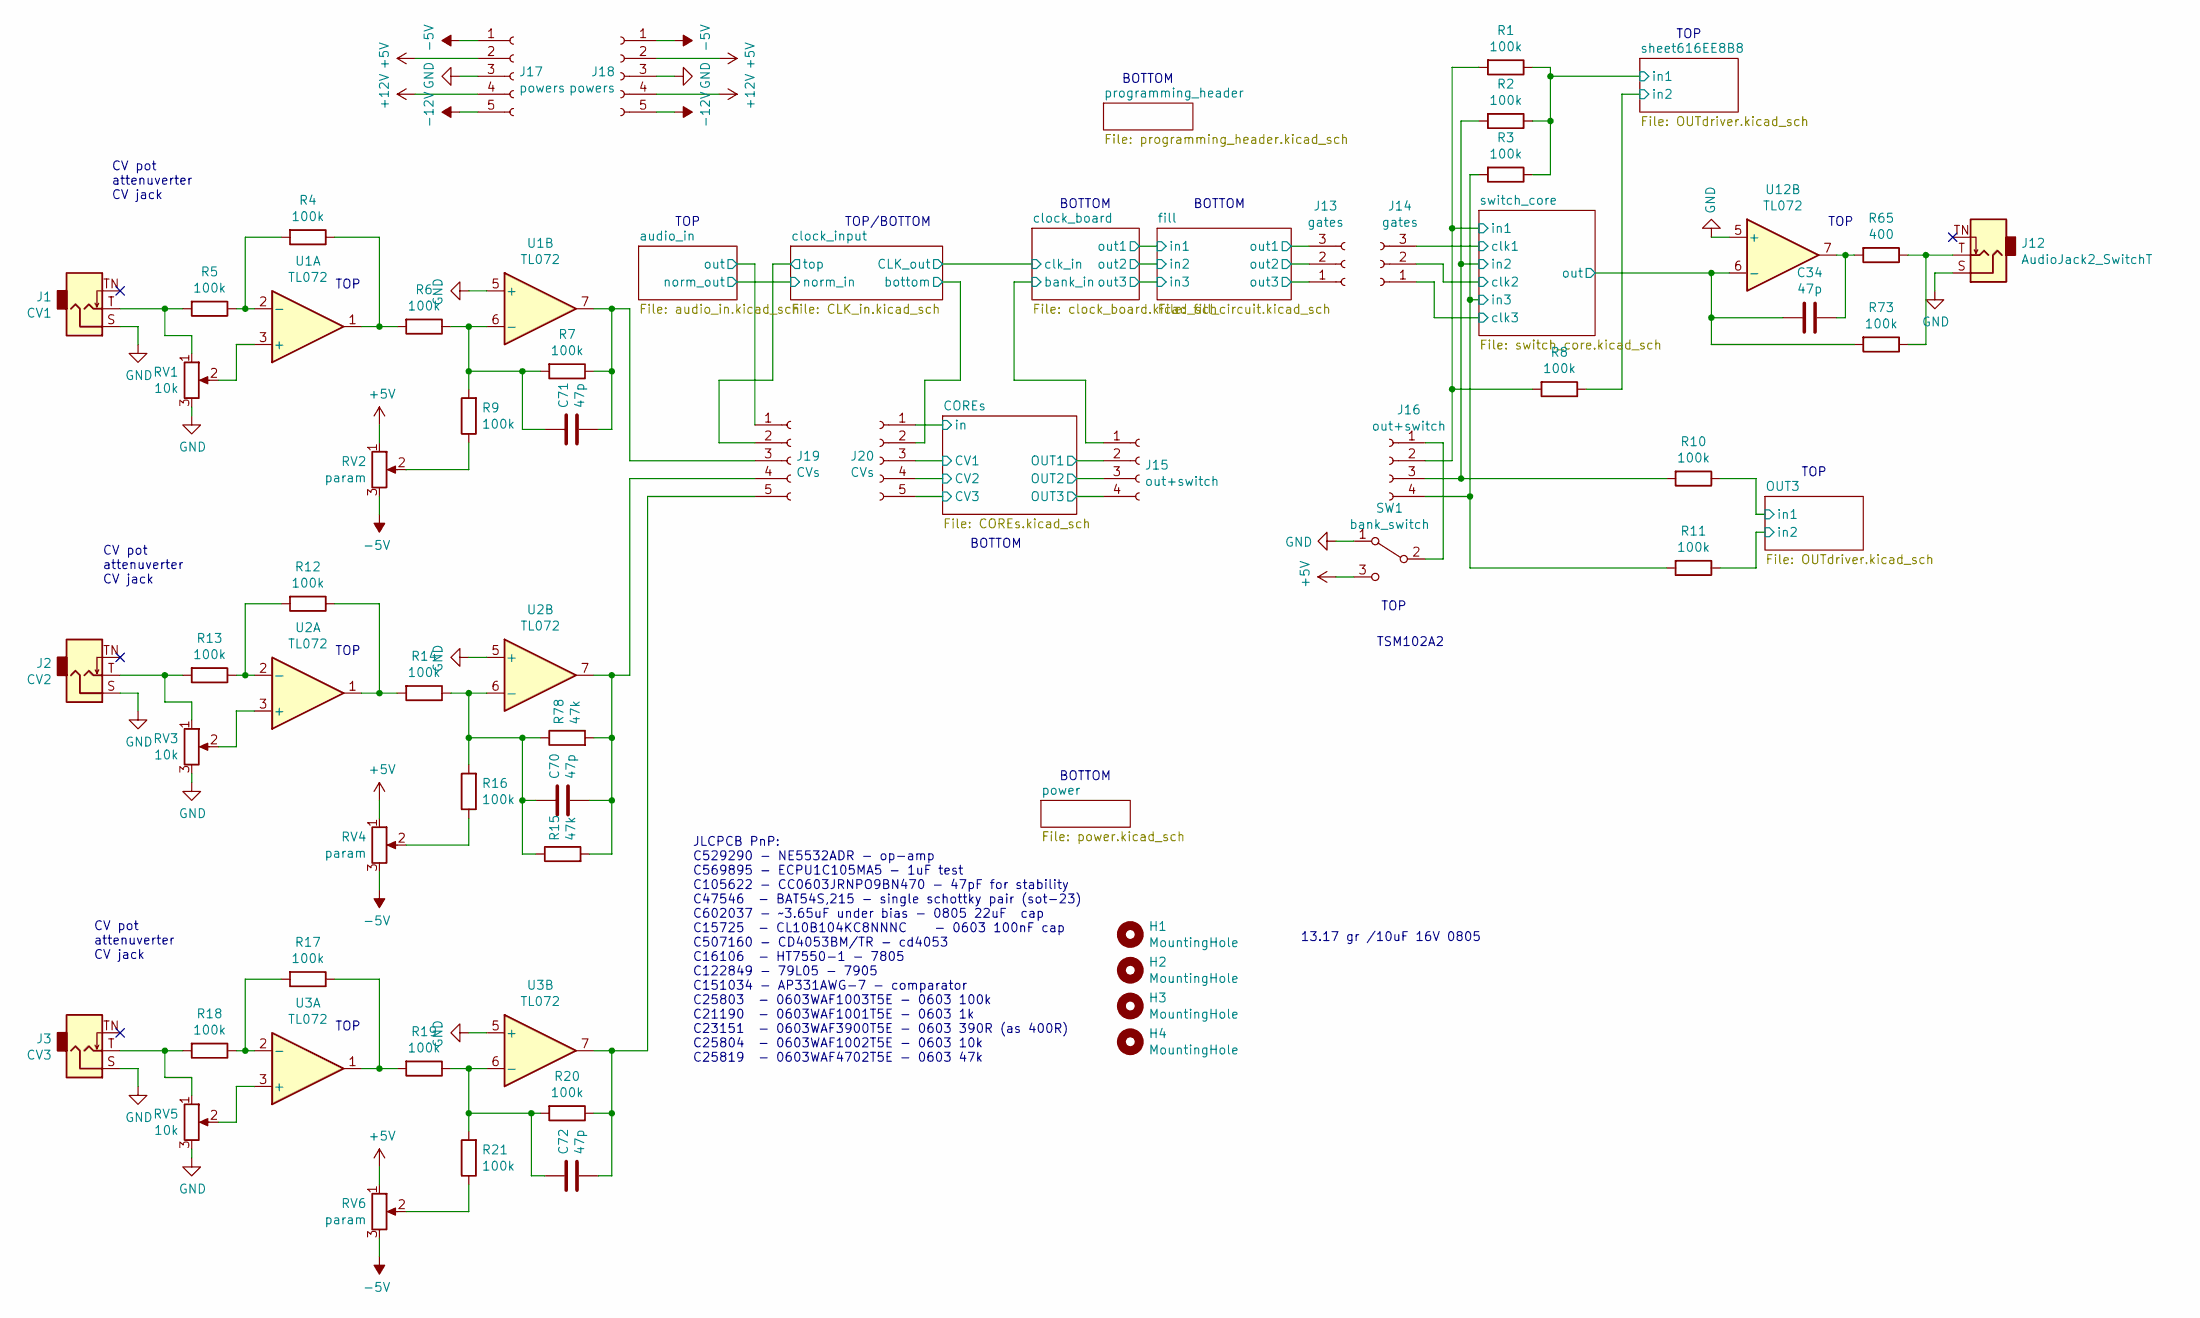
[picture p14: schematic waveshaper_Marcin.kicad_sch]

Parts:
C34, C70, C71, C72: 47p; C_0603_1608Metric
H1, H2, H3, H4: MountingHole; SS-16F03_cutout
J1: CV1; thonkiconn
J2: CV2; thonkiconn
J3: CV3; thonkiconn
J12: AudioJack2_SwitchT; thonkiconn
J13, J14: gates; PinHeader_1x03_P2.54mm_Vertical
J15, J16: out+switch; PinHeader_1x04_P2.54mm_Vertical
J17, J18: powers; PinHeader_1x05_P2.54mm_Vertical
J19, J20: CVs; PinHeader_1x05_P2.54mm_Vertical
R1, R2, R3, R4, R5, R6, R7, R8, R9, R10, R11, R12, R13, R14, R16, R17, R18, R19, R20, R21, R73: 100k; R_0603_1608Metric
R15, R78: 47k; R_0603_1608Metric
R65: 400; R_0603_1608Metric
RV1, RV3, RV5: 10k; Potentiometer_Alps_RK09K_Single_Vertical
RV2, RV4, RV6: param; Potentiometer_Alps_RK09K_Single_Vertical
SW1: bank_switch; TSM1x3
U1, U2, U3, U12: TL072; SOIC-8_3.9x4.9mm_P1.27mm

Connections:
+5V: J17.2, J18.2, RV2.1, RV4.1, RV6.1, SW1.3 (C); also elsewhere on the board
+12V: J17.4, J18.4; also elsewhere on the board
-5V: J17.1, J18.1, RV2.3, RV4.3, RV6.3; also elsewhere on the board
-12V: J17.5, J18.5; also elsewhere on the board
/COREs/CV1: J20.3; also elsewhere on the board
/COREs/CV2: J20.4; also elsewhere on the board
/COREs/CV3: J20.5; also elsewhere on the board
/COREs/OUT1: J15.2; also elsewhere on the board
/COREs/OUT2: J15.3; also elsewhere on the board
/COREs/OUT3: J15.4; also elsewhere on the board
/COREs/in: J20.1; also elsewhere on the board
/OUT3/in1: R10.1; also elsewhere on the board
/OUT3/in2: R11.1; also elsewhere on the board
/audio_in/out: J19.1; also elsewhere on the board
/clock_board/bank_in: J15.1; also elsewhere on the board
/clock_input/bottom: J20.2; also elsewhere on the board
/clock_input/top: J19.2; also elsewhere on the board
/fill/out1: J13.3; also elsewhere on the board
/fill/out2: J13.2; also elsewhere on the board
/fill/out3: J13.1; also elsewhere on the board
/sheet616EE8B8/in1: R1.1, R2.1, R3.1; also elsewhere on the board
/sheet616EE8B8/in2: R8.1; also elsewhere on the board
/switch_core/clk1: J14.3; also elsewhere on the board
/switch_core/clk2: J14.2; also elsewhere on the board
/switch_core/clk3: J14.1; also elsewhere on the board
/switch_core/in1: J16.2, R1.2, R8.2; also elsewhere on the board
/switch_core/in2: J16.3, R2.2, R10.2; also elsewhere on the board
/switch_core/in3: J16.4, R3.2, R11.2; also elsewhere on the board
/switch_core/out: C34.2, R73.2, U12.6 (-); also elsewhere on the board
GND: J1.S, J2.S, J3.S, J12.S, J17.3, J18.3, RV1.3, RV3.3, RV5.3, SW1.1 (A), U1.5 (+), U2.5 (+), U3.5 (+), U12.5 (+); also elsewhere on the board
unnamed: C34.1, R65.2, U12.7
unnamed: C70.1, R14.1, R15.1, R16.2, R78.1, U2.6 (-)
unnamed: C70.2, J19.4, R15.2, R78.2, U2.7
unnamed: C71.1, R6.1, R7.2, R9.2, U1.6 (-)
unnamed: C71.2, J19.3, R7.1, U1.7
unnamed: C72.1, R19.1, R20.2, R21.2, U3.6 (-)
unnamed: C72.2, J19.5, R20.1, U3.7
unnamed: J1.T, R5.2, RV1.1
unnamed: J2.T, R13.2, RV3.1
unnamed: J3.T, R18.2, RV5.1
unnamed: J12.T, R65.1, R73.1
unnamed: J16.1, SW1.2 (B)
unnamed: R4.1, R6.2, U1.1
unnamed: R4.2, R5.1, U1.2 (-)
unnamed: R9.1, RV2.2
unnamed: R12.1, R14.2, U2.1
unnamed: R12.2, R13.1, U2.2 (-)
unnamed: R16.1, RV4.2
unnamed: R17.1, R19.2, U3.1
unnamed: R17.2, R18.1, U3.2 (-)
unnamed: R21.1, RV6.2
unnamed: RV1.2, U1.3 (+)
unnamed: RV3.2, U2.3 (+)
unnamed: RV5.2, U3.3 (+)

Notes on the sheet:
CV pot attenuverter CV jack
TOP
JLCPCB PnP: C529290 - NE5532ADR - op-amp C569895 - ECPU1C105MA5 - 1uF test C105622 - CC0603JRNPO9BN470 - 47pF for stability C47546 - BAT54S,215 - single schottky pair (sot-23) C602037 - ~3.65uF under bias - 0805 22uF cap C15725 - CL10B104KC8NNNC - 0603 100nF cap C507160 - CD4053BM/TR - cd4053 C1610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
BOTTOM
13.17 gr /10uF 16V 0805
TOP/BOTTOM
TSM102A2

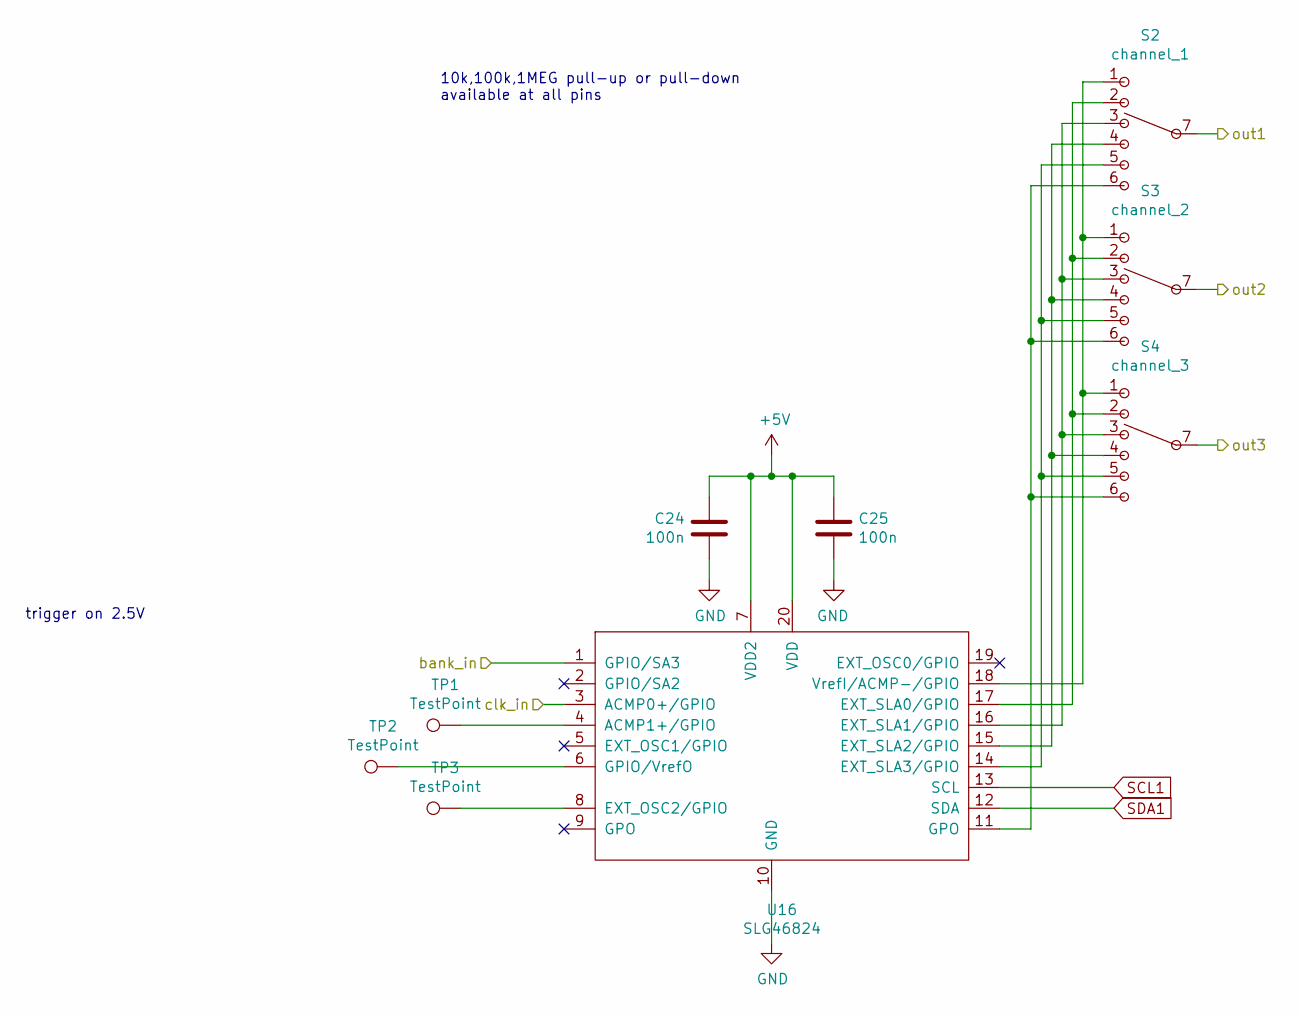
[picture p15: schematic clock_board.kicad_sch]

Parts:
C24, C25: 100n; C_0603_1608Metric
S2: channel_1; SS-16F03
S3: channel_2; SS-16F03
S4: channel_3; SS-16F03
TP1, TP2, TP3: TestPoint; TestPoint_Pad_D2.0mm
U16: SLG46824; TSSOP-20_4.4x6.5mm_P0.65mm

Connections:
+5V: C24.1, C25.1, U16.7 (VDD2), U16.20 (VDD); also elsewhere on the board
/clock_board/bank_in: U16.1 (GPIO/SA3); also elsewhere on the board
/clock_board/clk_in: U16.3 (ACMP0+/GPIO); also elsewhere on the board
/clock_board/out1: S2.7; also elsewhere on the board
/clock_board/out2: S3.7; also elsewhere on the board
/clock_board/out3: S4.7; also elsewhere on the board
GND: C24.2, C25.2, U16.10 (GND); also elsewhere on the board
unnamed: S2.1, S3.1, S4.1, U16.18 (VrefI/ACMP-/GPIO)
unnamed: S2.2, S3.2, S4.2, U16.17 (EXT_SLA0/GPIO)
unnamed: S2.3, S3.3, S4.3, U16.16 (EXT_SLA1/GPIO)
unnamed: S2.4, S3.4, S4.4, U16.15 (EXT_SLA2/GPIO)
unnamed: S2.5, S3.5, S4.5, U16.14 (EXT_SLA3/GPIO)
unnamed: S2.6, S3.6, S4.6, U16.11 (GPO)
unnamed: TP1.1, U16.4 (ACMP1+/GPIO)
unnamed: TP2.1, U16.6 (GPIO/VrefO)
unnamed: TP3.1, U16.8 (EXT_OSC2/GPIO)
SCL1: U16.13 (SCL); also elsewhere on the board
SDA1: U16.12 (SDA); also elsewhere on the board

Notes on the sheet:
trigger on 2.5V
10k,100k,1MEG pull-up or pull-down available at all pins

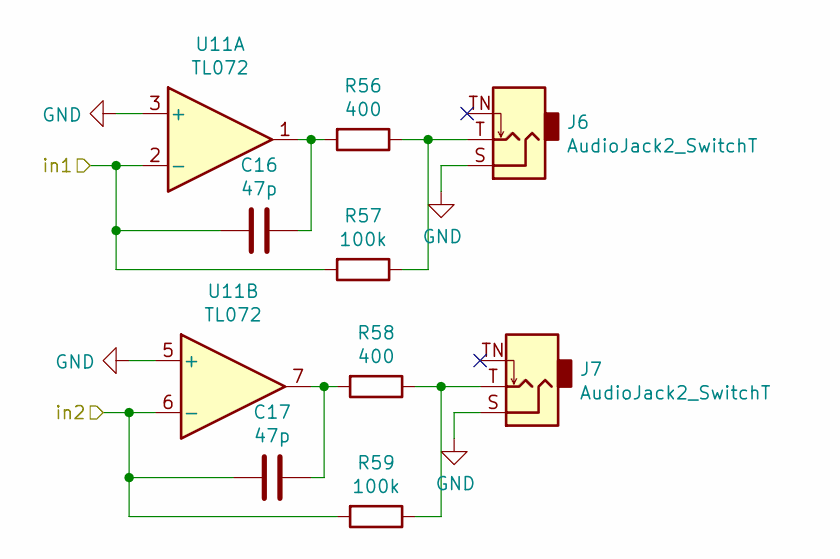
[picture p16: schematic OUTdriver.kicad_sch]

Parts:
C16, C17: 47p; C_0603_1608Metric
J6, J7: AudioJack2_SwitchT; thonkiconn
R56, R58: 400; R_0603_1608Metric
R57, R59: 100k; R_0603_1608Metric
U11: TL072; SOIC-8_3.9x4.9mm_P1.27mm

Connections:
/sheet616EE8B8/in1: C16.2, R57.2, U11.2 (-); also elsewhere on the board
/sheet616EE8B8/in2: C17.2, R59.2, U11.6 (-); also elsewhere on the board
GND: J6.S, J7.S, U11.3 (+), U11.5 (+); also elsewhere on the board
unnamed: C16.1, R56.2, U11.1
unnamed: C17.1, R58.2, U11.7
unnamed: J6.T, R56.1, R57.1
unnamed: J7.T, R58.1, R59.1

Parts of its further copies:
C22, C23: 47p; C_0603_1608Metric
J10, J11: AudioJack2_SwitchT; thonkiconn
R68, R70: 400; R_0603_1608Metric
R69, R71: 100k; R_0603_1608Metric

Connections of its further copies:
/OUT3/in1: C22.2, R69.2; also elsewhere on the board
/OUT3/in2: C23.2, R71.2; also elsewhere on the board
GND: J10.S, J11.S; also elsewhere on the board
unnamed 43: C22.1, R68.2; also elsewhere on the board
unnamed 44: C23.1, R70.2; also elsewhere on the board
unnamed: J10.T, R68.1, R69.1
unnamed: J11.T, R70.1, R71.1

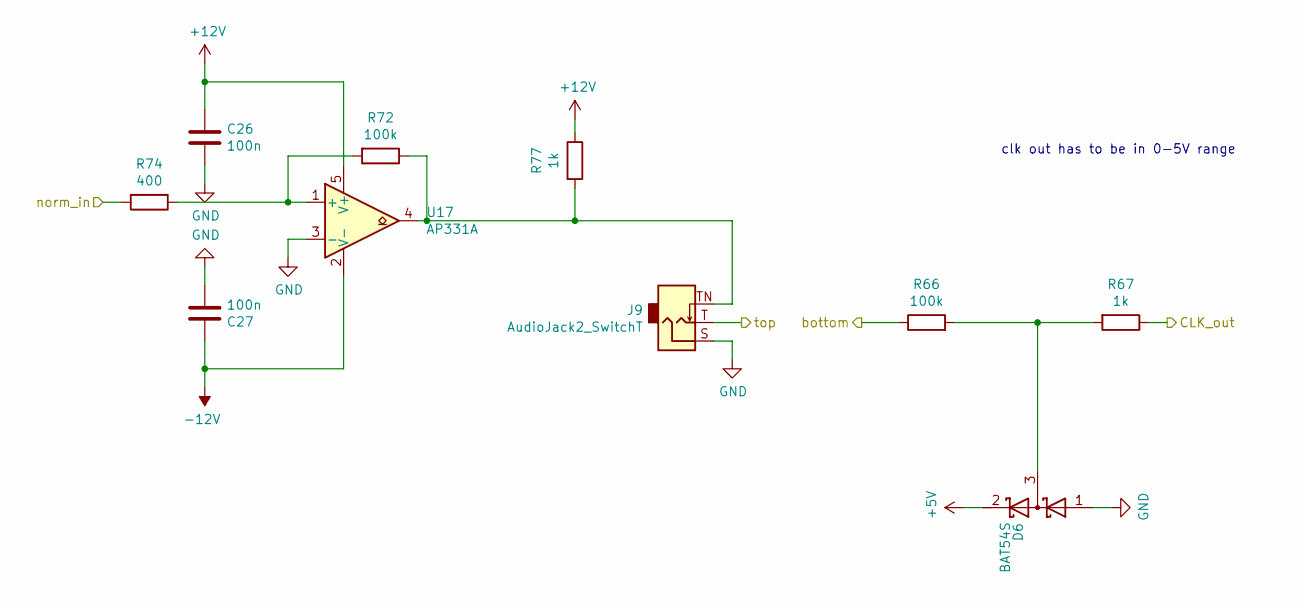
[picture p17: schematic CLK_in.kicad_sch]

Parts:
C26, C27: 100n; C_0603_1608Metric
D6: BAT54S; SOT-23
J9: AudioJack2_SwitchT; thonkiconn
R66, R72: 100k; R_0603_1608Metric
R67, R77: 1k; R_0603_1608Metric
R74: 400; R_0603_1608Metric
U17: AP331A; SOT-23-5

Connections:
+5V: D6.2 (K); also elsewhere on the board
+12V: C26.1, R77.1, U17.5 (V+); also elsewhere on the board
-12V: C27.1, U17.2 (V-); also elsewhere on the board
/audio_in/norm_out: R74.2; also elsewhere on the board
/clock_board/clk_in: R67.1; also elsewhere on the board
/clock_input/bottom: R66.1; also elsewhere on the board
/clock_input/top: J9.T; also elsewhere on the board
GND: C26.2, C27.2, D6.1 (A), J9.S, U17.3 (-); also elsewhere on the board
unnamed: D6.3 (common), R66.2, R67.2
unnamed: J9.TN, R72.1, R77.2, U17.4
unnamed: R72.2, R74.1, U17.1 (+)

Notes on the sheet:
clk out has to be in 0-5V range

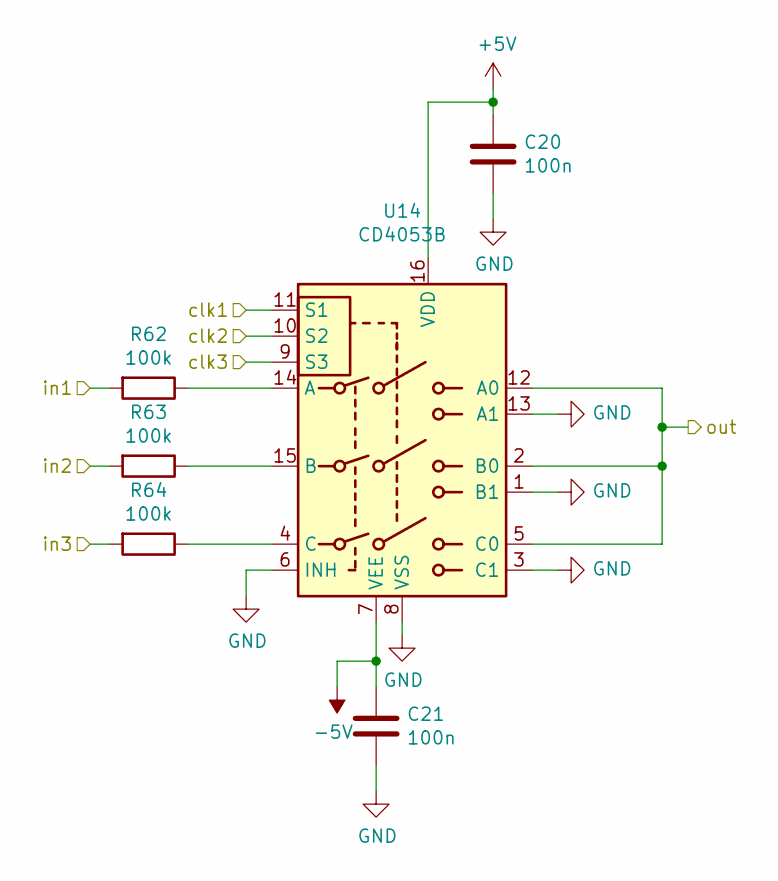
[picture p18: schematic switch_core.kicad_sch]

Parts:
C20, C21: 100n; C_0603_1608Metric
R62, R63, R64: 100k; R_0603_1608Metric
U14: CD4053B; SOP-16_3.9x9.9mm_P1.27mm

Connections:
+5V: C20.1, U14.16 (VDD); also elsewhere on the board
-5V: C21.1, U14.7 (VEE); also elsewhere on the board
/switch_core/clk1: U14.11 (S1); also elsewhere on the board
/switch_core/clk2: U14.10 (S2); also elsewhere on the board
/switch_core/clk3: U14.9 (S3); also elsewhere on the board
/switch_core/in1: R62.2; also elsewhere on the board
/switch_core/in2: R63.2; also elsewhere on the board
/switch_core/in3: R64.2; also elsewhere on the board
/switch_core/out: U14.2 (B0), U14.5 (C0), U14.12 (A0); also elsewhere on the board
GND: C20.2, C21.2, U14.1 (B1), U14.3 (C1), U14.6 (INH), U14.8 (VSS), U14.13 (A1); also elsewhere on the board
unnamed: R62.1, U14.14 (A)
unnamed: R63.1, U14.15 (B)
unnamed: R64.1, U14.4 (C)

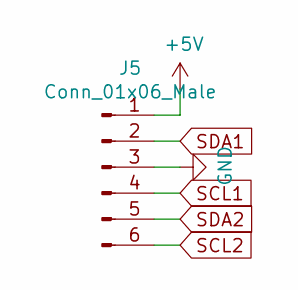
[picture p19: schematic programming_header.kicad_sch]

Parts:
J5: Conn_01x06_Male; PinHeader_2x03_P2.00mm_Vertical

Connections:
+5V: J5.1; also elsewhere on the board
GND: J5.3; also elsewhere on the board
SCL1: J5.4; also elsewhere on the board
SCL2: J5.6; also elsewhere on the board
SDA1: J5.2; also elsewhere on the board
SDA2: J5.5; also elsewhere on the board

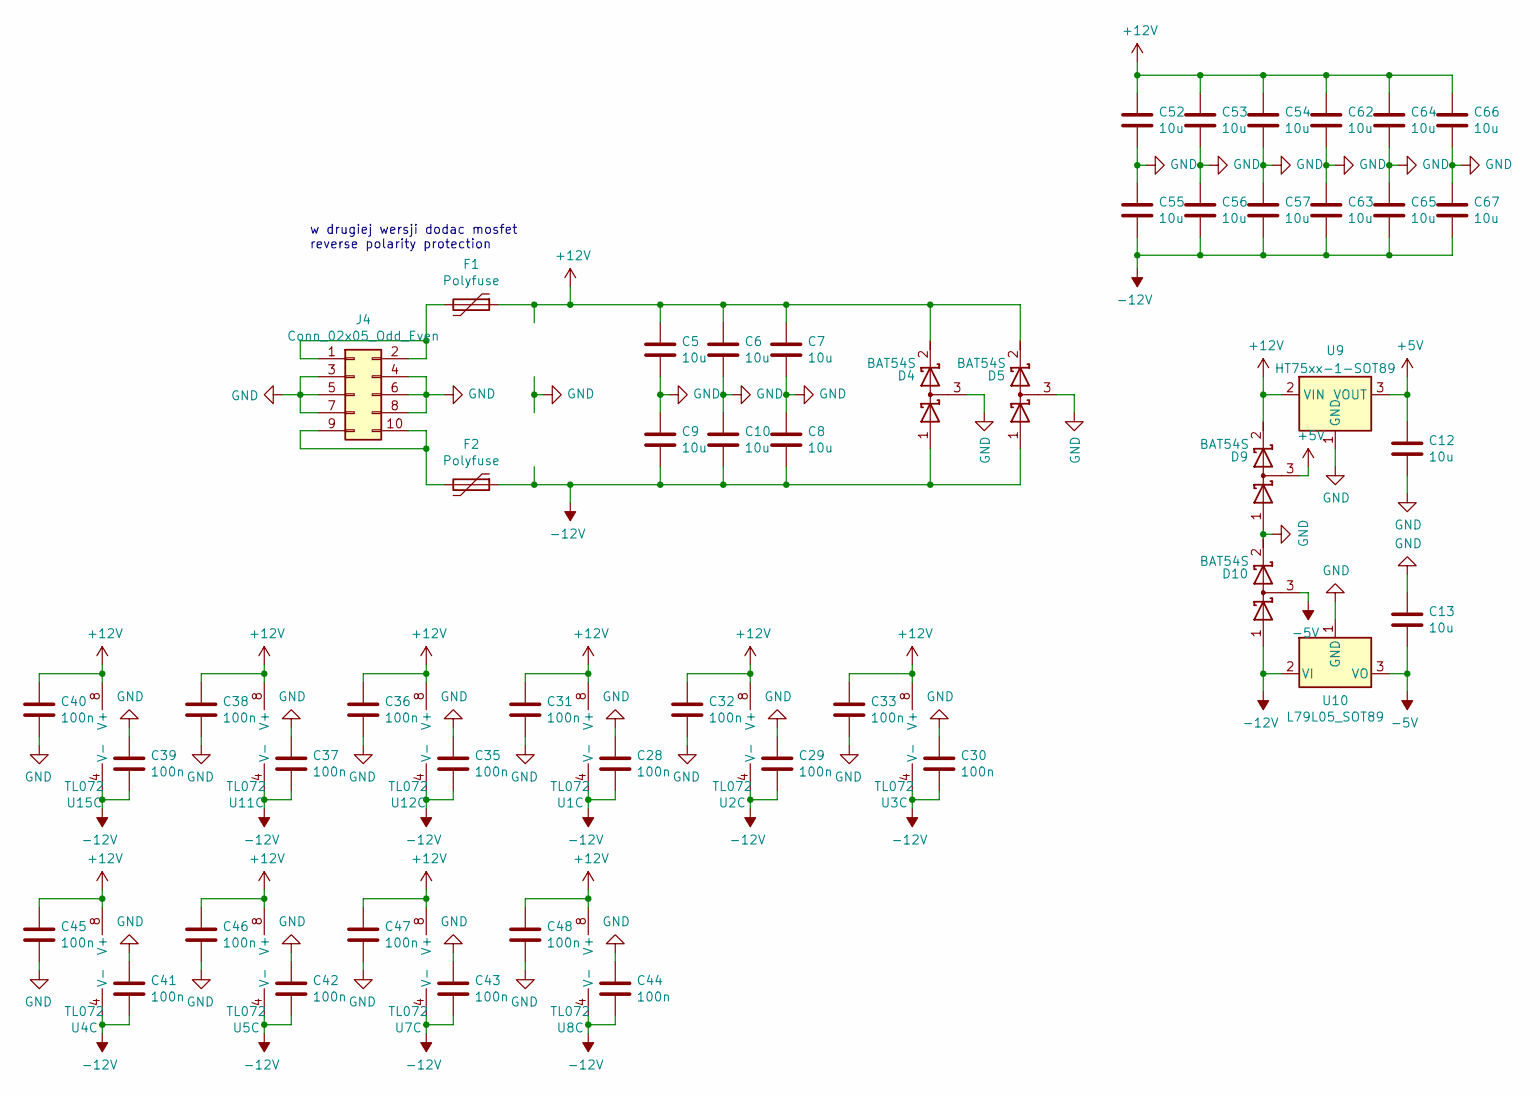
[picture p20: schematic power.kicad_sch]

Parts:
C5, C6, C7, C8, C9, C10, C12, C13, C52, C53, C54, C55, C56, C57, C62, C63, C64, C65, C66, C67: 10u; C_0805_2012Metric
C28, C29, C30, C31, C32, C33, C35, C36, C37, C38, C39, C40, C41, C42, C43, C44, C45, C46, C47, C48: 100n; C_0603_1608Metric
D4, D5, D9, D10: BAT54S; SOT-23
F1, F2: Polyfuse; Fuse_0805_2012Metric
J4: Conn_02x05_Odd_Even; PinHeader_2x05_P2.54mm_Vertical_SMD
U1, U2, U3, U4, U5, U7, U8, U11, U12, U15: TL072; SOIC-8_3.9x4.9mm_P1.27mm
U9: HT75xx-1-SOT89; SOT-89-3
U10: L79L05_SOT89; SOT-89-3

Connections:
+5V: C12.1, D9.3 (common), U9.3 (VOUT); also elsewhere on the board
+12V: C5.1, C6.1, C7.1, C31.1, C32.1, C33.1, C36.1, C38.1, C40.1, C45.1, C46.1, C47.1, C48.1, C52.1, C53.1, C54.1, C62.1, C64.1, C66.1, D4.2 (K), D5.2 (K), D9.2 (K), F1.1, U1.8 (V+), U2.8 (V+), U3.8 (V+), U4.8 (V+), U5.8 (V+), U7.8 (V+), U8.8 (V+), U9.2 (VIN), U11.8 (V+), U12.8 (V+), U15.8 (V+); also elsewhere on the board
-5V: C13.2, D10.3 (common), U10.3 (VO); also elsewhere on the board
-12V: C8.2, C9.2, C10.2, C28.2, C29.2, C30.2, C35.2, C37.2, C39.2, C41.2, C42.2, C43.2, C44.2, C55.2, C56.2, C57.2, C63.2, C65.2, C67.2, D4.1 (A), D5.1 (A), D10.1 (A), F2.1, U1.4 (V-), U2.4 (V-), U3.4 (V-), U4.4 (V-), U5.4 (V-), U7.4 (V-), U8.4 (V-), U10.2 (VI), U11.4 (V-), U12.4 (V-), U15.4 (V-); also elsewhere on the board
GND: C5.2, C6.2, C7.2, C8.1, C9.1, C10.1, C12.2, C13.1, C28.1, C29.1, C30.1, C31.2, C32.2, C33.2, C35.1, C36.2, C37.1, C38.2, C39.1, C40.2, C41.1, C42.1, C43.1, C44.1, C45.2, C46.2, C47.2, C48.2, C52.2, C53.2, C54.2, C55.1, C56.1, C57.1, C62.2, C63.1, C64.2, C65.1, C66.2, C67.1, D4.3 (common), D5.3 (common), D9.1 (A), D10.2 (K), J4.3, J4.4, J4.5, J4.6, J4.7, J4.8, U9.1 (GND), U10.1 (GND); also elsewhere on the board
unnamed: F1.2, J4.1, J4.2
unnamed: F2.2, J4.9, J4.10

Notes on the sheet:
w drugiej wersji dodac mosfet reverse polarity protection

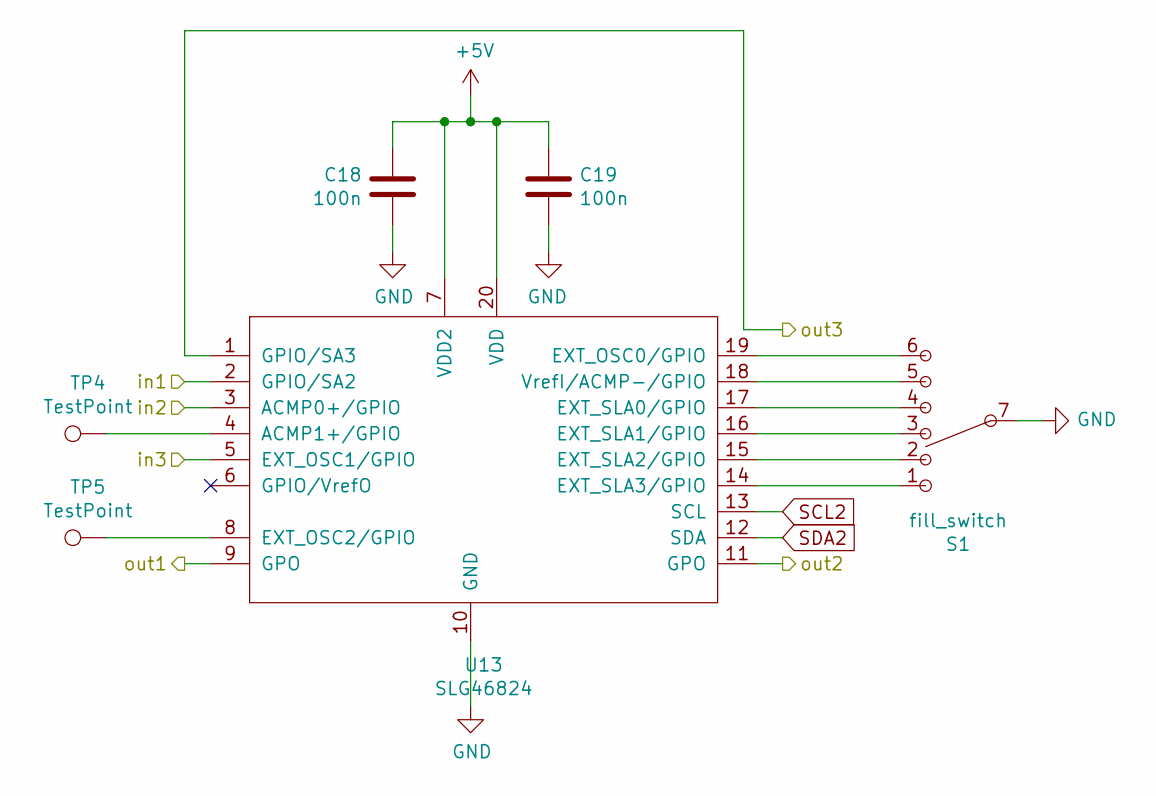
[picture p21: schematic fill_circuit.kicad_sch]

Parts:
C18, C19: 100n; C_0603_1608Metric
S1: fill_switch; SS-16F03
TP4, TP5: TestPoint; TestPoint_Pad_D2.0mm
U13: SLG46824; TSSOP-20_4.4x6.5mm_P0.65mm

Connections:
+5V: C18.1, C19.1, U13.7 (VDD2), U13.20 (VDD); also elsewhere on the board
/clock_board/out1: U13.2 (GPIO/SA2); also elsewhere on the board
/clock_board/out2: U13.3 (ACMP0+/GPIO); also elsewhere on the board
/clock_board/out3: U13.5 (EXT_OSC1/GPIO); also elsewhere on the board
/fill/out1: U13.9 (GPO); also elsewhere on the board
/fill/out2: U13.11 (GPO); also elsewhere on the board
/fill/out3: U13.1 (GPIO/SA3); also elsewhere on the board
GND: C18.2, C19.2, S1.7, U13.10 (GND); also elsewhere on the board
unnamed: S1.1, U13.14 (EXT_SLA3/GPIO)
unnamed: S1.2, U13.15 (EXT_SLA2/GPIO)
unnamed: S1.3, U13.16 (EXT_SLA1/GPIO)
unnamed: S1.4, U13.17 (EXT_SLA0/GPIO)
unnamed: S1.5, U13.18 (VrefI/ACMP-/GPIO)
unnamed: S1.6, U13.19 (EXT_OSC0/GPIO)
unnamed: TP4.1, U13.4 (ACMP1+/GPIO)
unnamed: TP5.1, U13.8 (EXT_OSC2/GPIO)
SCL2: U13.13 (SCL); also elsewhere on the board
SDA2: U13.12 (SDA); also elsewhere on the board

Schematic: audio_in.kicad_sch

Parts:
J8: AudioJack2_SwitchT; thonkiconn
R60, R61: 100k; R_0603_1608Metric
RV8: gain; Potentiometer_Alps_RK09K_Single_Vertical
U12: TL072; SOIC-8_3.9x4.9mm_P1.27mm

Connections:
/audio_in/norm_out: R61.1, RV8.1, U12.1; also elsewhere on the board
/audio_in/out: RV8.2; also elsewhere on the board
GND: J8.S, RV8.3, U12.3 (+); also elsewhere on the board
unnamed: J8.T, R60.2
unnamed: R60.1, R61.2, U12.2 (-)

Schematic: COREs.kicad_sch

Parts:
C1, C2: 100n; C_0603_1608Metric
C3, C58, C59, C60, C61: 1u - test; C_1210_3225Metric
C14, C15, C49, C50, C51, C68, C69: 47p; C_0603_1608Metric
D1, D2, D3, D7, D8: BAT54S; SOT-23
JP1, JP2, JP3, JP4, JP5: Jumper; SolderJumper-2_P1.3mm_Open_RoundedPad1.0x1.5mm
R22, R23, R26, R33, R34, R35, R36, R47, R48, R49, R50, R51, R52, R53, R54: 100k; R_0603_1608Metric
R24, R25, R31, R40, R41, R42, R44, R45, R55, R75, R76: 10k; R_0603_1608Metric
R27, R28, R29, R30, R32, R37, R46: 1k; R_0603_1608Metric
R38, R39: 47k; R_0603_1608Metric
R43: 250k; R_0603_1608Metric
U4, U5, U7, U8: TL072; SOIC-8_3.9x4.9mm_P1.27mm
U6: AS3363; SOIC-16_3.9x9.9mm_P1.27mm

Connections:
+5V: R75.2; also elsewhere on the board
+12V: C1.1, U6.16 (Vcc); also elsewhere on the board
-5V: R40.2; also elsewhere on the board
-12V: C2.1, U6.8 (Vee); also elsewhere on the board
/COREs/CV1: R25.2; also elsewhere on the board
/COREs/CV2: R37.1; also elsewhere on the board
/COREs/CV3: D3.3 (common), R38.1; also elsewhere on the board
/COREs/OUT1: JP1.2; also elsewhere on the board
/COREs/OUT2: JP3.1; also elsewhere on the board
/COREs/OUT3: JP2.2; also elsewhere on the board
/COREs/in: D7.3 (common), JP4.2, JP5.2, R31.1, R50.1; also elsewhere on the board
GND: C1.2, C2.2, D2.3 (common), R26.2, R27.2, R28.1, R29.1, R30.1, R41.2, R44.2, R45.1, R46.2, R54.2, R76.2, U4.3 (+), U5.3 (+), U5.5 (+), U6.1 (GND), U7.3 (+), U8.3 (+), U8.5 (+); also elsewhere on the board
unnamed: C3.1, C50.1, C58.2, C59.1, C60.2, C61.1, R51.1, U8.1
unnamed: C3.2, C58.1, C59.2, C60.1, C61.2, R55.1
unnamed: C14.1, R22.1, R23.2, U4.6 (-)
unnamed: C14.2, R23.1, R24.2, U4.7
unnamed: C15.1, JP1.1, R34.1, U5.7
unnamed: C15.2, R34.2, U5.6 (-), U6.5 (Iout1)
unnamed: C49.1, R36.1, R47.2, U5.1
unnamed: C49.2, R36.2, U5.2 (-), U6.6 (Iout3)
unnamed: C50.2, R51.2, U6.12 (Iout2), U8.2 (-)
unnamed: C51.1, R42.2, R49.1, U7.7
unnamed: C51.2, R49.2, R53.1, U7.6 (-)
unnamed: C68.1, R47.1, R48.2, R50.2, U7.2 (-)
unnamed: C68.2, JP2.1, R48.1, U7.1
unnamed: C69.1, R52.2, R55.2, U8.6 (-)
unnamed: C69.2, JP3.2, R52.1, U8.7
unnamed: D1.1 (A), U4.1
unnamed: D1.3 (common), R24.1, R25.1, R27.1, U4.2 (-), U6.3 (CVMix1)
unnamed: D2.1 (A), D2.2 (K), R31.2, R32.1
unnamed: D3.1 (A), R53.2
unnamed: D3.2 (K), R54.1, U7.5 (+)
unnamed: D7.1 (A), R22.2
unnamed: D7.2 (K), R26.1, U4.5 (+)
unnamed: D8.1 (A), R35.1
unnamed: D8.2 (K), R33.1
unnamed: D8.3 (common), JP4.1
unnamed: JP5.1, R39.2, R43.2
unnamed: R28.2, R32.2, U6.2 (IN1)
unnamed: R29.2, R35.2, U6.10 (IN3B)
unnamed: R30.2, R33.2, U6.9 (IN3A)
unnamed: R37.2, U6.13 (Vcntrl2)
unnamed: R38.2, R44.1, U6.11 (CVMix3)
unnamed: R39.1, R45.2, U6.14 (CVMix2)
unnamed: R40.1, R41.1, R42.1, U6.7 (Vcntrl3)
unnamed: R43.1, R46.1, U6.15 (IN2)
unnamed: R75.1, R76.1, U6.4 (Vcntrl1)

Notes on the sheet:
CV3 needs to be +-10V
doubler circuit
X circuit
ABS circuit
CV2 needs to be +-2V

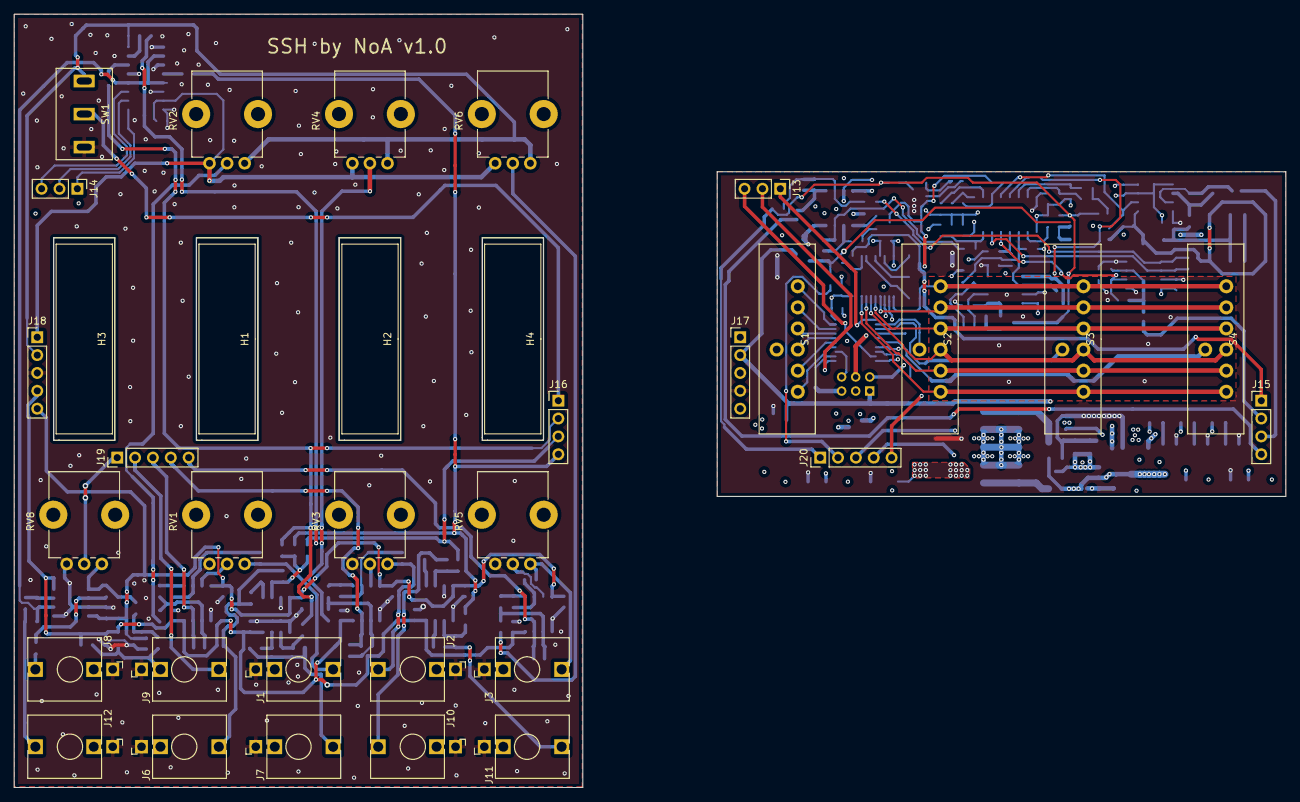
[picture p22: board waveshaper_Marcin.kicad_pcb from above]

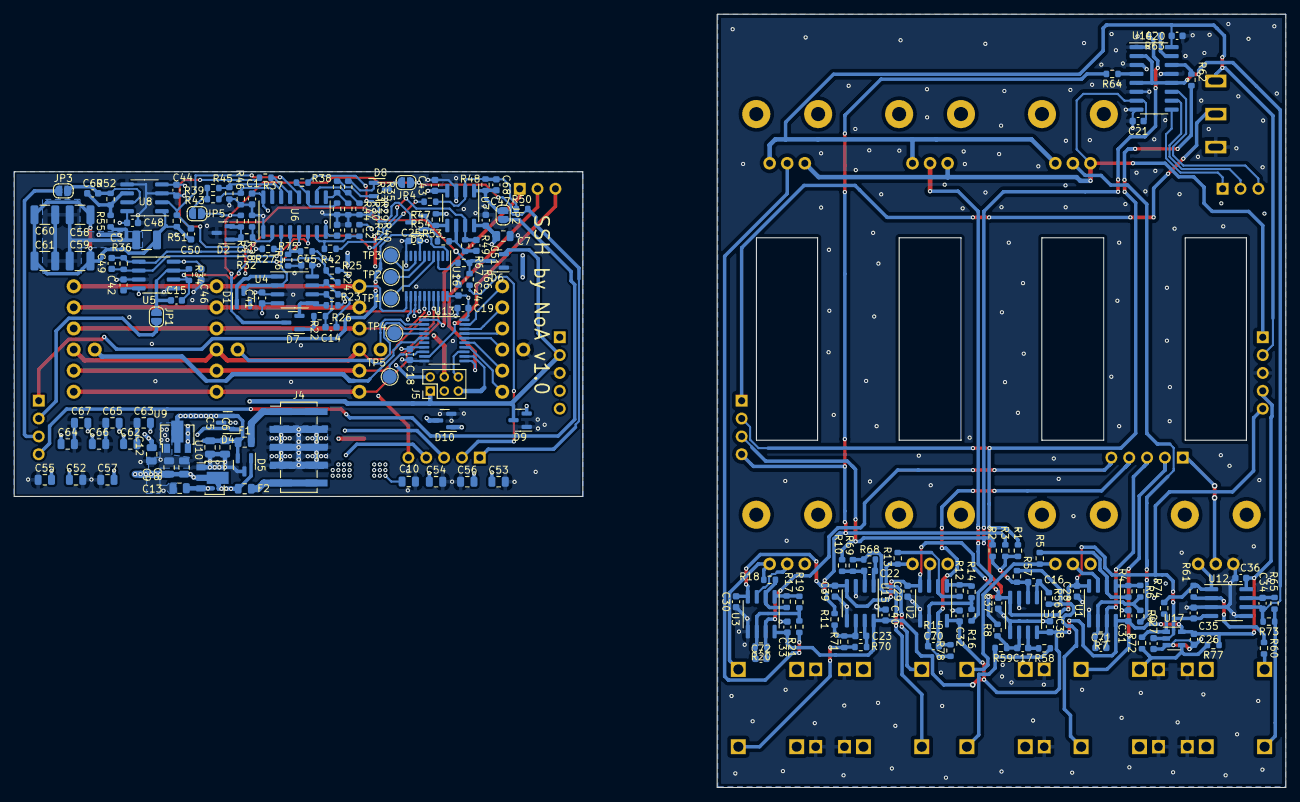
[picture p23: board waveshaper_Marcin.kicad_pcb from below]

Board: 4 copper layers, 180.9 x 110.0 mm, 223 parts (189 on the bottom side), 133 nets.

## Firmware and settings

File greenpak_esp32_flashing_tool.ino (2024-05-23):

#include "I2C_SLG46826.h"
#define GUZICZEK_PIN 26
I2C_SLG46826 slg(Wire);

#define SLG46826_I2C_SDA 32
#define SLG46826_I2C_SCL 33

void setup() {
  // Init Serial
  Serial.begin(115200);
  delay(500);
  pinMode(GUZICZEK_PIN, INPUT_PULLUP);
  // Init I2C
  Wire.begin(SLG46826_I2C_SDA, SLG46826_I2C_SCL);
}

void readSLG(int controlCode) {
  Serial.printf("===============================================================\n");
  Serial.printf("SLG46826 READ [Control Code = %d]\n", controlCode);
  Serial.printf("===============================================================\n");
  uint8_t data[256];
  memset(data, 0, sizeof(data));
  if (slg.readSlg(controlCode, data)) {
    for (int i = 0; i < 16; i++) {
      for (int j = 0; j < 16; j++) {
        Serial.printf("%02X", data[i * 16 + j]);
      }
      Serial.println();
    }
  } else {
    Serial.printf("SLG46826 not found.\n");
  }
}

void eraseSLG(int controlCode) {
  Serial.printf("===============================================================\n");
  Serial.printf("SLG46826 ERASE [Control Code = %d]\n", controlCode);
  Serial.printf("===============================================================\n");
  if (slg.eraseSlg(controlCode)) {
    Serial.printf("SLG46826 erased.\n");
    slg.resetSlg(controlCode);
    Serial.printf("Resetting SLG46826.\n");
  } else {
    Serial.printf("SLG46826 not found.\n");
  }
}

bool writeSLG(int controlCode, String hexString) {
  Serial.printf("===============================================================\n");
  Serial.printf("SLG46826 WRITE [Control Code = %d]\n", controlCode);
  Serial.printf("===============================================================\n");
  delay(10);
  //int pom=slg.scanSlg(controlCode);
  //Serial.printf("slg code %d\n", pom);
  if (slg.eraseSlg(controlCode)) {
    Serial.printf("SLG46826 erased.\n");
    slg.resetSlg(controlCode);
    Serial.printf("Resetting SLG46826.\n");

    uint8_t hexData[16][16];
    memset(hexData, 0, sizeof(hexData));
    uint16_t hexStrLen = hexString.length();

    uint16_t pos = 0;
    for (int i = 0; i < 16; i++) {
      // find :
      while (pos < hexStrLen && hexString[pos] != ':') {
        pos++;
      }

      // data check
      if (hexStrLen < (pos + 43)) {
        Serial.println("Error");
        while (1)
          ;
      }

      // data skip
      pos += 9;

      // hex to data
      for (int j = 0; j < 16; j++) {
        uint8_t byteData = 0;
        if ('A' <= hexString[pos]) {
          byteData += (hexString[pos] - 'A' + 10) * 16;
        } else {
          byteData += (hexString[pos] - '0') * 16;
        }
        pos++;
        if ('A' <= hexString[pos]) {
          byteData += hexString[pos] - 'A' + 10;
        } else {
          byteData += hexString[pos] - '0';
        }
        pos++;
        hexData[i][j] = byteData;
      }
    }

    // print
    for (int i = 0; i < 16; i++) {
      for (int j = 0; j < 16; j++) {
        Serial.printf("%02X", hexData[i][j]);
      }
      Serial.println();
    }

    slg.writeSlg(0, &hexData[0][0]);
    slg.resetSlg(0);
    Serial.printf("Resetting SLG46826.\n");
  } 
    else 
    {
      Serial.println("dupa nie wgralo sie");
      return 1;
      }
  Serial.println("wgralo sie");
  return 0;
}

void resetSLG(int controlCode) {
  Serial.printf("===============================================================\n");
  Serial.printf("SLG46826 RESET [Control Code = %d]\n", controlCode);
  Serial.printf("===============================================================\n");
  if (slg.resetSlg(controlCode)) {
    Serial.printf("Resetting SLG46826.\n");
  } else {
    Serial.printf("SLG46826 not found.\n");
  }
}

void gpioSLG(int controlCode) {
  Serial.printf("===============================================================\n");
  Serial.printf("SLG46826 GPIO [Control Code = %d]\n", controlCode);
  Serial.printf("===============================================================\n");
  for (int i = 0; i <= 14; i++) {
    Serial.printf("%d : IO%2d\n", slg.digitalRead(controlCode, i), i);
  }
}

int ctrlCode(){
  for (int i = 0; i < 16; i++) {
    int pom=slg.scanSlg(i);
    
    if (pom){
      Serial.printf("slg code %d, ale\n", i);
      return i;
    }
  }
 return -1;
}


void loop() {
    String kod_CLK_DIV =":100000009BB3FDDBB451DBF9038F033D4E86FD5BF3:100010008639685BFD1B20418FB3A5D1F64790D58B:100020004A50FB3B6D03000000E8000000000000A8:100030003E000000B0AACF7FFD2C00FCC00FFCC02A:100040000F00CE0F000000000000000000000000C4:1000500000000000000000000000000000000000A0:1000600000803000808000000000808000000000E0:10007000000300300000000000000000000000004D:10008000000000000014223C0C00002400000000CE:100090000620050000966A7FC8AC1F002102000000:1000A00000AA6A2000010000D00201001002040131:1000B00000AC020100AC02000100AC0201005502DC:1000C0000001000002000100000001010100000029:1000D0000000000000000000000000000000000020:1000E0000000000000000000000000000000000010:1000F000000000000000000000000000000000A55B:00000001FF";
    String kod_FILL_GEN =":10000000D2691492233DC9C23017B058408201AA68:1000100034A492804A0460408FE3481124458F1431:1000200001000000000000000000000000000000CF:10003000000000000000000000D40400000000D216:100040000F000050FD000000000000000000000054:1000500000000000000000000000000000000000A0:10006000008061006161616100008080300030309B:100070000030300000000000000000000000000020:1000800000000000001422300C00000000000000FE:100090000270000001010101ACAC0700AC000000DF:1000A0000003022000010000800201008002000124:1000B00000800201000002000100000201000002B5:1000C0000001000002000100000001010100000029:1000D0000000000000000000000000000000000020:1000E0000000000000000000000000000000000010:1000F000000000000000000000000000000000A55B:00000001FF";

    String kod_test1 =":100000009BB3FDDBB451DBF9038F033D4E86FD5BF3:1000100086396853FD1B20418FB3A5D1F64790D593:100020004850F33B0D00000000E800000000000015:100030003E000000B0AACF7FFD2C00FCC00FFCDF0B:100040000F00CE0F000000000000000000000000C4:1000500000000000000000000000000000000000A0:1000600000803000808000000000808000000000E0:10007000000300300000000000000000000000004D:100080000000F802381422340C00000000000000C8:100090000620050000966A7FC8AC1F002102000000:1000A00000AA6A2000010000D00201001002040131:1000B00000AC020100AC02000100AC020100000231:1000C0000001000002000100000001010100000029:1000D0000000000000000000000000000000000020:1000E0000000000000000000000000000000000010:1000F000000000000000000000000000000000A55B:00000001FF";
    String kod_test2 =":1000000000000000000000000000000000000000F0:10001000000000000000000000000000000000D010:10002000004003000000000000000000000000008D:100030003E000000B0AAC00FFC0000FCC00FFCC0D6:100040000F00C00F000000000000000000000000D2:1000500000000000000000000000000000000000A0:1000600000803000808000000000808000000000E0:10007000000300300000000000000000000000004D:1000800000000000001422340C00000000000000FA:100090000620050000966A7FC8AC1F002102000000:1000A00000AA6A2000010000D00201001002040131:1000B00000AC020100AC02000100AC020100000231:1000C0000001000002000100000001010100000029:1000D0000000000000000000000000000000000020:1000E0000000000000000000000000000000000010:1000F000000000000000000000000000000000A55B";

    int ctrl1=0, ctrl2=0;
    bool written1=0, written2=0;
    //, kod2;
    pinMode(25, OUTPUT);
    while (1) {
    ctrl1=ctrlCode();
    ctrl2=slg.scanSlg(1);
    Serial.printf("ctrl1 %d, ctrl2 %d, written%d\n", ctrl1, ctrl2,written1);
    digitalWrite(25, written1);
    if (written1){
      while (digitalRead(GUZICZEK_PIN)) delay(1);
      delay(5);
      while (!digitalRead(GUZICZEK_PIN)) delay(5);
      delay(5);
      written1=0;
    }
    else if (!written1 && ctrl1!=-1){
      if (!writeSLG(ctrl1, kod_CLK_DIV))
        written1=1;
    }
    delay(100);
  }
}
